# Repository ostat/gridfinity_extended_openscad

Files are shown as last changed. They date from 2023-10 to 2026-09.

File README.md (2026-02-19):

# Gridfinity Extended OpenSCAD Model

Welcome to the Gridfinity Extended OpenSCAD project! This is a recreation of Zack Freedman's Gridfinity system in OpenSCAD, designed to accurately reproduce the original Gridfinity bins while adding extra features and customization options.

## Features
- Accurate reproduction of Zack Freedman's original Gridfinity bins.
- Additional features and customization options for the base model.
- Extension patterns for further personalization and modularity.

## Getting Started
**Gridfinity Extended** is a set of OpenSCAD scripts for generating gridfinity related 3d models. There are two main ways to use the scripts.
- There is the official online customiser hosted at [makerworld](https://makerworld.com/en/models/481168-gridfinity-extended#profileId-1037829).
- Alternatively you can download and run the scripts locally.

### Option 1: Online customiser
You can also use the online version of this project hosted on [MakerWorld](https://makerworld.com). This option allows you to quickly experiment with the models without downloading anything.
The scripts uploaded to are fully featured and supported. I keep these updated with the latest version from GitHub.<br>
- Link: https://makerworld.com/en/models/481168-gridfinity-extended#profileId-1037829

### Option 2: Running locally
Running locally is how I recommend running the scripts. The scripts run faster and you can save your configuration. However but it does require you download and install the OpenSCAD software on your local machine.

1. Install OpenSCAD. This project relies on features available in the **OpenSCAD Developer Version**. Make sure to download it from [OpenSCAD Developer Version](https://openscad.org/downloads.html#snapshots).

2. Clone or download this repository to your local machine:
   ```bash
   git clone https://github.com/ostat/gridfinity_extended_openscad.git
   ```
   Alternatively, you can download the ZIP file from the repository page and extract it.

3. Enable OpenSCAD Features.
   - Open OpenSCAD application
   - Go to `Menu > Edit > Preferences`.
   - In the **Preferences** dialog go to the **Advanced** Tab:
     - Backend: select **manifold** option. Makes OpenSCAD faster.
   - An then go to the **Features** Tab:
     - Check **textmetrics**: Enables text related features for the base text.

4. Start Creating Your Own Gridfinity Parts
   - Open the SCAD library file you want to modify, e.g.: `gridfinity_baseplate.scad`
   - Make sure the Customizer window is visible:
      - View → Customizer (if not already open).
   - Render the model:
     - Press F5 for a quick preview
     - Press F6 for a full render
   - Adjust the parameters in the Customizer:
       - Parameter	Example Value	Description<BR>
        Width	2	Number of modules wide<BR>
        Depth	1	Number of modules deep<BR>
        Magnets	Enabled	Include magnet holes<BR>
        The model will update in real-time based on your changes.<BR>

5. Start exploring and customising the Gridfinity bins and extensions!

## Official Documentation
Official detailed documentation for each of the scripts can be found here [gridfinity-extended](https://docs.ostat.com/docs/openscad/gridfinity-extended)

## Scripts Overview
### Gridfinity Basic Cup
Script: `gridfinity_basic_cup.scad`<br>
This script creates the basic **Gridfinity Cup** with customizable dimensions, magnet slots, and divider options. It serves as the foundation for most Gridfinity bins.<br>
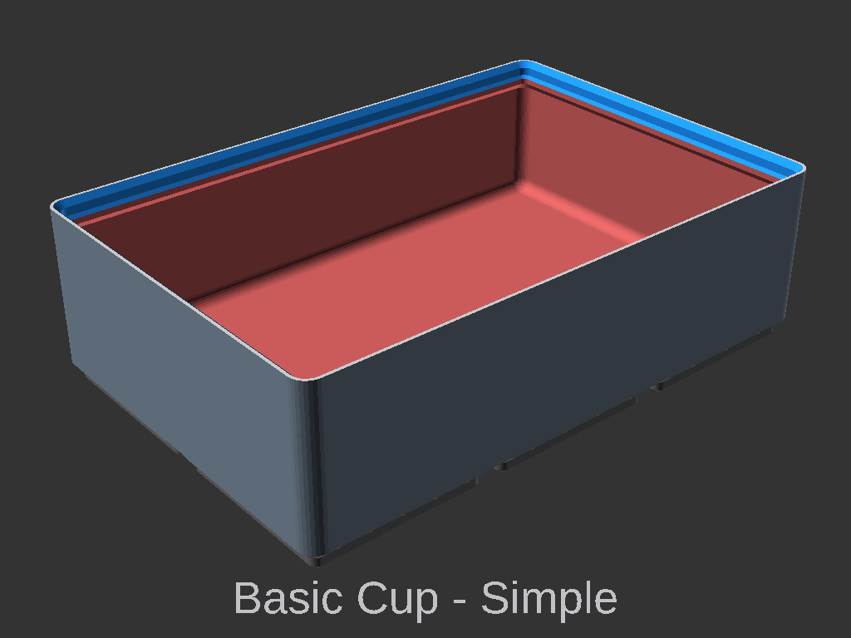
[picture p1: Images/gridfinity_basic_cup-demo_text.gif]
[](./Images/gridfinity_basic_cup-demo_text.gif)

### Gridfinity Base Plate
Script: `gridfinity_baseplate.scad`<br>
This script generates customizable Gridfinity baseplates. It includes options for magnet placement, weighted bases, and various styles to suit different applications.. Supports creating of customisable shapes.<br>
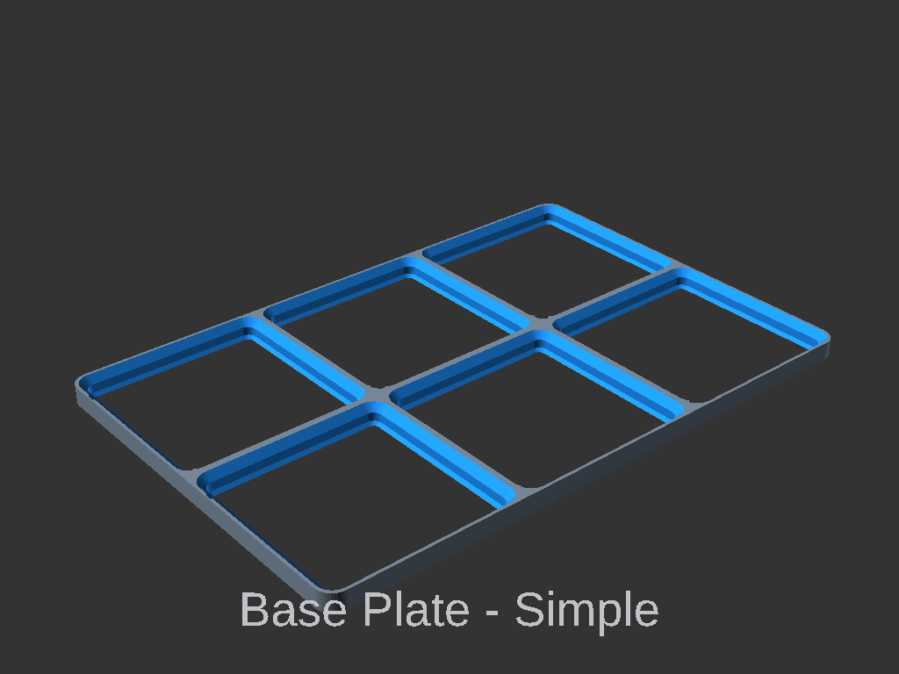
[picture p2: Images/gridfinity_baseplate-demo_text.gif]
[](./Images/gridfinity_baseplate-demo_text.gif)

### Gridfinity Drawers
Script: `gridfinity_drawers.scad`<br>
Creates modular drawers for Gridfinity bins. Includes options for drawer sizes, handles, and dividers, allowing for efficient organization.

### Gridfinity Extended Item Holder
Script: `gridfinity_item_holder.scad`<br>
Customisable Grid based item holder. Has built in dimensions of many common Memory card, Cartridges, batteries, and tools.<br>
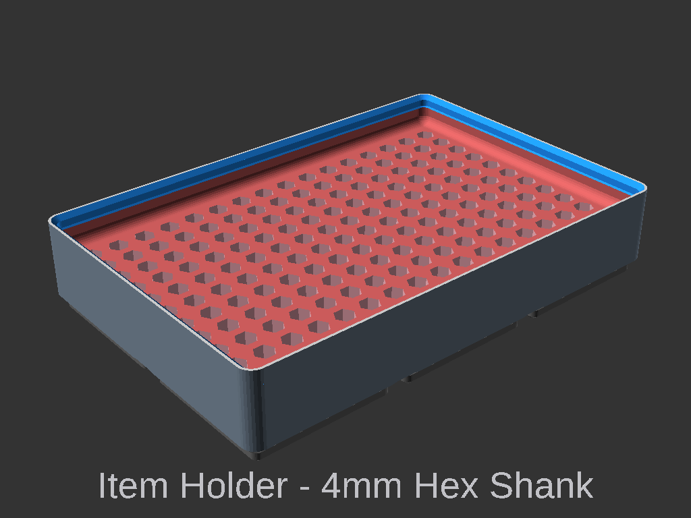
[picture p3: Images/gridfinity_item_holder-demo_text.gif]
[](./Images/gridfinity_item_holder-demo_text.gif)

### Gridfinity Extended Tray
Script: `gridfinity_tray.scad`<br>
Catch all tray for holding small items.<br>
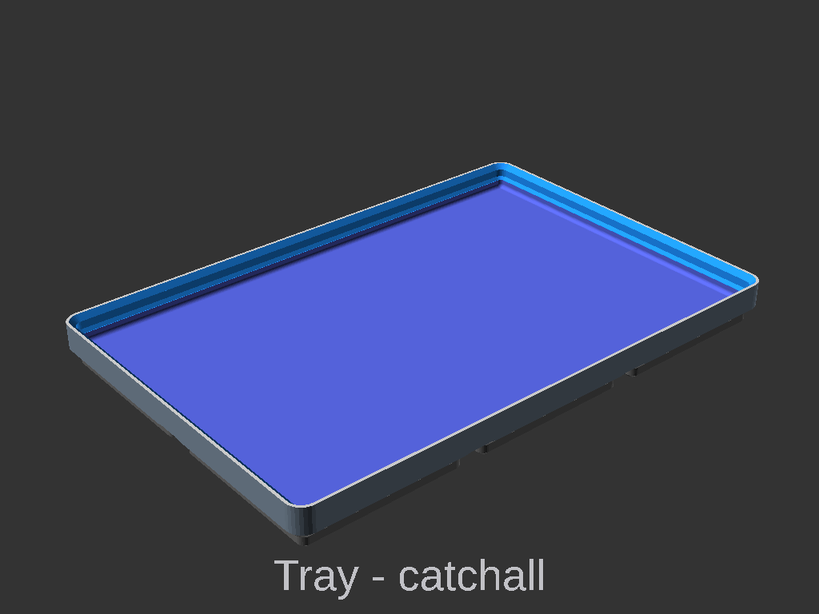
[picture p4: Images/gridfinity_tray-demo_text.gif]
[](./Images/gridfinity_tray-demo_text.gif)

### Gridfinity Marble Run
Script: `gridfinity_marble.scad`<br>
A fun and creative script for generating marble runs that are compatible with the Gridfinity system. Great for educational or entertainment purposes.

### gridfinity_lid.scad
Creates lids for Gridfinity bins. Includes options for sliding lids, hinged lids, and magnet-secured lids to keep items secure.

### gridfinity_silverware.scad
Creates organizers for silverware that fit within the Gridfinity system. Perfect for kitchen organization.

### gridfinity_chess.scad
Generates a Gridfinity-compatible chess set. Each piece is designed to fit within the Gridfinity system, making it easy to store and organise.

### gridfinity_sliding_lid.scad
A specialized script for creating sliding lids for Gridfinity bins. Includes options for locking mechanisms and smooth sliding functionality.

### gridfinity_socket_holder.scad
Generates holders for sockets and other tools, ensuring compatibility with the Gridfinity system. Includes predefined dimensions for common socket sizes.

### gridfinity_baseplate_flsun_q5.scad
A specialized version of the baseplate script tailored for the FLsun Q5 3D printer. It ensures compatibility with the printer's build dimensions and features.

## How to Contribute

I welcome contributions to help improve and expand the Gridfinity Extended library! Here’s how you can contribute:

1. **Fork the Repository**: Create your own fork of the project to make changes.
2. **Make Improvements**: Add new features, fix bugs, or improve documentation.
3. **Submit a Pull Request**: Once your changes are ready, submit a pull request to the main repository for review.

## Feedback and Support

Your feedback is invaluable! If you have suggestions, issues, or ideas for improvement, feel free to open an issue or contribute to the project.

---

Thank you for exploring the Gridfinity Extended OpenSCAD project! I hope you enjoy customising and expanding your Gridfinity system.

This project is based on work by Zack Freedman's of [voidstarlab](https://www.voidstarlab.com/) and [vector76](https://github.com/vector76/)'s [gridfinity_openscad](https://github.com/vector76/gridfinity_openscad)

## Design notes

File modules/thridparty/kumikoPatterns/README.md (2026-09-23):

# Kumiko Patterns

This is an OpenSCAD implementation of various traditional japanese Kumiko patterns.
They are all based on the triangle shape and add various infills.
Implemented right now are the following patterns:

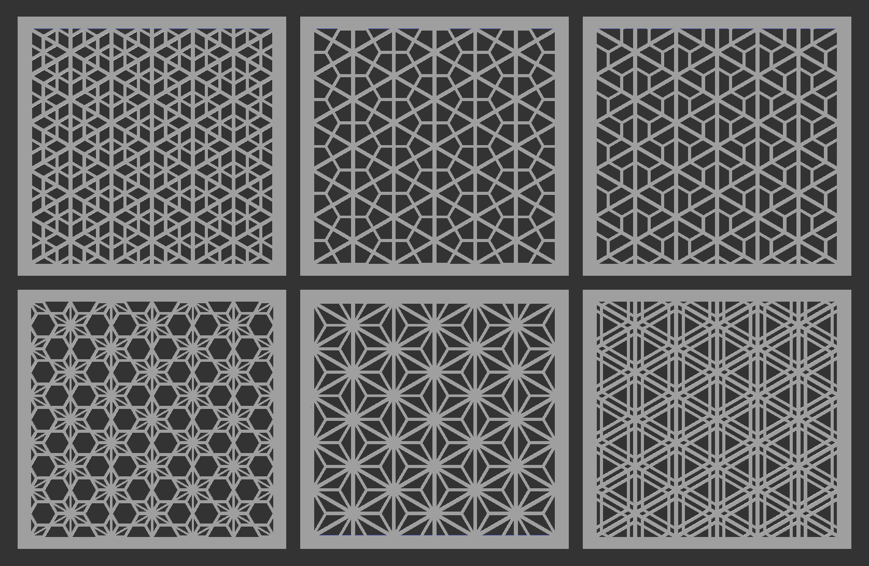
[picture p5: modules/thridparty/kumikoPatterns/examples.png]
examples of kumiko patterns


- Mikado
- Tsumiishi Kikko
- Bishamon Kikkou
- Tobi Asanoha
- Asanoha
- Goma

(left to right, top to bottom)

I am sorry if I butchered those names or got the naming entirely wrong, 
please contact me if I need to fix them or just create a PR :)

## Usage

To use those patterns in your OpenSCAD scripts, copy the `kumiko.scad` file 
into the same directory as your script, then include it with `use <kumiko.scad>`.
To create a pattern of your choice, invoke the respective module like so:

`goma(cellSize=20, widthInCells=6, heightInCells=5, gap=3, strength=1.6, fillingStrength=1.2);`

See the [demo.scad](demo.scad) file for more usage examples.

- `cellSize` is the edge length of the base triangle shape
- `widthInCells` is the width of the created pattern, in full triangles. A value of 4 will create a pattern that is 4 triangles wide.
- `heightInCells` is similar to `widthInCells`, just for the height of the pattern.
- `gap` is specific to the Goma pattern and specifies the space between parallel lines, not taking the line strength into account.
- `strength` is the width of the base triangle lines.
- `fillingStrength` is the width of the lines inside the base triangles.

## Implementation notes

The triangle-based patterns are created by first building a base triangle pattern, 
and then building the infill patterns by rotating a given line pattern 
around the intersection points of the base triangles.

If you want to implement additional point-symmetric patterns, 
please align the implementation with the existing ones to ease code understandability and maintainability.
If you want to implement patterns not based on non-overlapping triangles,
you are free to do it any way you like (until a common pattern is established).

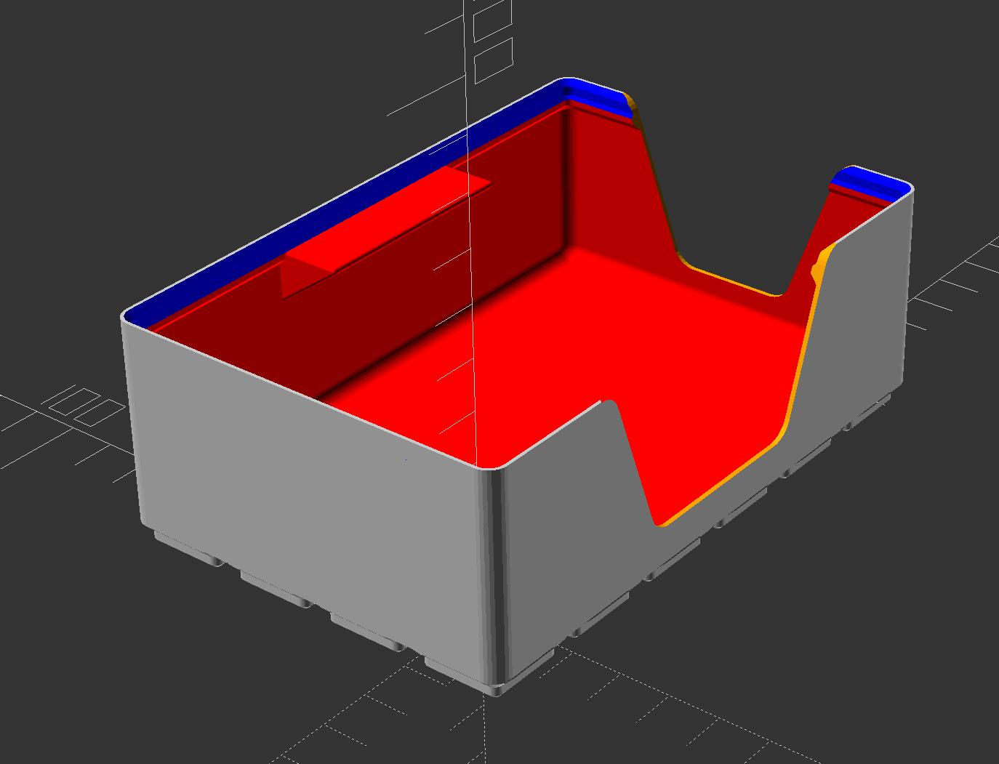
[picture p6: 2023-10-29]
Images/basic_cup_wall_cutout.jpg

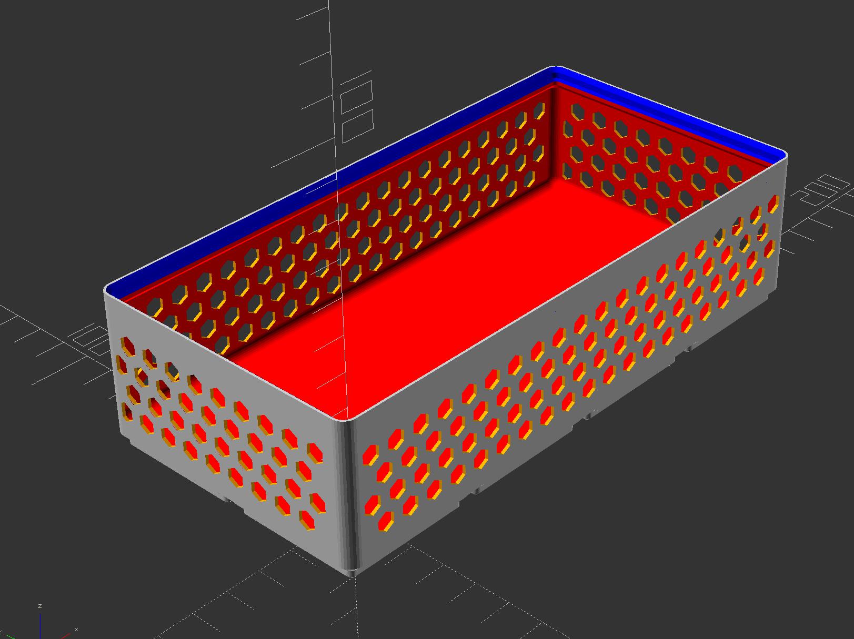
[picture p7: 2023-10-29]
Images/basic_cup_wall_pattern.jpg

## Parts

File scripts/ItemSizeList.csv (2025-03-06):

type | code | shape | diameter | width | thickness | height | depthneeded | description | source
battery | aaaa | round | 8.3 | 0 | 0 | 42.5 | 10.625 | AAAA cell | https://en.wikipedia.org/wiki/List_of_battery_sizes
battery | aaa | round | 10.5 | 0 | 0 | 44.5 | 11.125 | AAA cell | https://en.wikipedia.org/wiki/List_of_battery_sizes
battery | aa | round | 14.5 | 0 | 0 | 50.5 | 12.625 | AA cell | https://en.wikipedia.org/wiki/List_of_battery_sizes
battery | 9v | square | 1 | 17.5 | 26.5 | 48.5 | 12.5 | 9v | https://en.wikipedia.org/wiki/List_of_battery_sizes
battery | c | round | 26.2 | 0 | 0 | 50 | 12.5 | C cell | https://en.wikipedia.org/wiki/List_of_battery_sizes
battery | d | round | 34.2 | 0 | 0 | 61.5 | 15.375 | d cell | https://en.wikipedia.org/wiki/List_of_battery_sizes
battery | 7540cell | round | 7.5 | 0 | 0 | 40 | 10 | 7540 cell | https://en.wikipedia.org/wiki/List_of_battery_sizes
battery | 8570cell | round | 8.5 | 0 | 0 | 70 | 17.5 | 8570 cell | https://en.wikipedia.org/wiki/List_of_battery_sizes
battery | 10180cell | round | 10 | 0 | 0 | 18 | 4.5 | 10180 cell | https://en.wikipedia.org/wiki/List_of_battery_sizes
battery | 10280cell | round | 10 | 0 | 0 | 28 | 7 | 10280 cell | https://en.wikipedia.org/wiki/List_of_battery_sizes
battery | 10440cell | round | 10 | 0 | 0 | 44 | 11 | 10440 cell | https://en.wikipedia.org/wiki/List_of_battery_sizes
battery | 10850cell | round | 10 | 0 | 0 | 85 | 21.25 | 10850 cell | https://en.wikipedia.org/wiki/List_of_battery_sizes
battery | 13400cell | round | 13 | 0 | 0 | 40 | 10 | 13400 cell | https://en.wikipedia.org/wiki/List_of_battery_sizes
battery | 14250cell | round | 14 | 0 | 0 | 25 | 6.25 | 14250 cell | https://en.wikipedia.org/wiki/List_of_battery_sizes
battery | 14300cell | round | 14 | 0 | 0 | 30 | 7.5 | 14300 cell | https://en.wikipedia.org/wiki/List_of_battery_sizes
battery | 14430cell | round | 14 | 0 | 0 | 43 | 10.75 | 14430 cell | https://en.wikipedia.org/wiki/List_of_battery_sizes
battery | 14500cell | round | 14 | 0 | 0 | 53 | 13.25 | 14500 cell | https://en.wikipedia.org/wiki/List_of_battery_sizes
battery | 14650cell | round | 14 | 0 | 0 | 65 | 16.25 | 14650 cell | https://en.wikipedia.org/wiki/List_of_battery_sizes
battery | 15270cell | round | 15 | 0 | 0 | 27 | 6.75 | 15270 cell | https://en.wikipedia.org/wiki/List_of_battery_sizes
battery | 16340cell | round | 16 | 0 | 0 | 34 | 8.5 | 16340 cell | https://en.wikipedia.org/wiki/List_of_battery_sizes
battery | 16650cell | round | 16 | 0 | 0 | 65 | 16.25 | 16650 cell | https://en.wikipedia.org/wiki/List_of_battery_sizes
battery | 17500cell | round | 17 | 0 | 0 | 50 | 12.5 | 17500 cell | https://en.wikipedia.org/wiki/List_of_battery_sizes
battery | 17650cell | round | 17 | 0 | 0 | 65 | 16.25 | 17650 cell | https://en.wikipedia.org/wiki/List_of_battery_sizes
battery | 17670cell | round | 17 | 0 | 0 | 67 | 16.75 | 17670 cell | https://en.wikipedia.org/wiki/List_of_battery_sizes
battery | 18350cell | round | 18 | 0 | 0 | 35 | 8.75 | 18350 cell | https://en.wikipedia.org/wiki/List_of_battery_sizes
battery | 18490cell | round | 18 | 0 | 0 | 49 | 12.25 | 18490 cell | https://en.wikipedia.org/wiki/List_of_battery_sizes
battery | 18500cell | round | 18 | 0 | 0 | 50 | 12.5 | 18500 cell | https://en.wikipedia.org/wiki/List_of_battery_sizes
battery | 18650cell | round | 18 | 0 | 0 | 65 | 16.25 | 18650 cell | https://en.wikipedia.org/wiki/List_of_battery_sizes
battery | 20700cell | round | 20 | 0 | 0 | 70 | 17.5 | 20700 cell | https://en.wikipedia.org/wiki/List_of_battery_sizes
battery | 21700cell | round | 21 | 0 | 0 | 70 | 17.5 | 21700 cell | https://en.wikipedia.org/wiki/List_of_battery_sizes
battery | 25500cell | round | 25 | 0 | 0 | 50 | 12.5 | 25500 cell | https://en.wikipedia.org/wiki/List_of_battery_sizes
battery | 26500cell | round | 26 | 0 | 0 | 50 | 12.5 | 26500 cell | https://en.wikipedia.org/wiki/List_of_battery_sizes
battery | 26650cell | round | 26 | 0 | 0 | 65 | 16.25 | 26650 cell | https://en.wikipedia.org/wiki/List_of_battery_sizes
battery | 26700cell | round | 26 | 0 | 0 | 70 | 17.5 | 26700 cell | https://en.wikipedia.org/wiki/List_of_battery_sizes
battery | 26800cell | round | 26 | 0 | 0 | 80 | 20 | 26800 cell | https://en.wikipedia.org/wiki/List_of_battery_sizes
battery | 32600cell | round | 32 | 0 | 0 | 60 | 15 | 32600 cell | https://en.wikipedia.org/wiki/List_of_battery_sizes
battery | 32650cell | round | 32 | 0 | 0 | 67.7 | 16.925 | 32650 cell | https://en.wikipedia.org/wiki/List_of_battery_sizes
battery | 32700cell | round | 32 | 0 | 0 | 70 | 17.5 | 32700 cell | https://en.wikipedia.org/wiki/List_of_battery_sizes
battery | 38120cell | round | 38 | 0 | 0 | 120 | 30 | 38120 cell | https://en.wikipedia.org/wiki/List_of_battery_sizes
battery | 38140cell | round | 38 | 0 | 0 | 140 | 35 | 38140 cell | https://en.wikipedia.org/wiki/List_of_battery_sizes
battery | 40152cell | round | 40 | 0 | 0 | 152 | 38 | 40152 cell | https://en.wikipedia.org/wiki/List_of_battery_sizes
battery | 4680cell | round | 46 | 0 | 0 | 80 | 20 | 4680 cell | https://en.wikipedia.org/wiki/List_of_battery_sizes
buttoncell | CR927 | halfround | 0 | 9.5 | 2.7 | 0 | 0 | CR927 cell | https://en.wikipedia.org/wiki/List_of_battery_sizes
buttoncell | CR1025 | halfround | 0 | 10 | 2.5 | 0 | 0 | CR1025 cell | https://en.wikipedia.org/wiki/List_of_battery_sizes
buttoncell | CR1130 | halfround | 0 | 11.5 | 3 | 0 | 0 | CR1130 cell | https://en.wikipedia.org/wiki/List_of_battery_sizes
buttoncell | CR1216 | halfround | 0 | 12.5 | 1.6 | 0 | 0 | CR1216 cell | https://en.wikipedia.org/wiki/List_of_battery_sizes
buttoncell | CR1220 | halfround | 0 | 12.5 | 2 | 0 | 0 | CR1220 cell | https://en.wikipedia.org/wiki/List_of_battery_sizes
buttoncell | CR1225 | halfround | 0 | 12.5 | 2.5 | 0 | 0 | CR1225 cell | https://en.wikipedia.org/wiki/List_of_battery_sizes
buttoncell | CR1616 | halfround | 0 | 16 | 1.6 | 0 | 0 | CR1616 cell | https://en.wikipedia.org/wiki/List_of_battery_sizes
buttoncell | CR1620 | halfround | 0 | 16 | 2 | 0 | 0 | CR1620 cell | https://en.wikipedia.org/wiki/List_of_battery_sizes
buttoncell | CR1632 | halfround | 0 | 16 | 3.2 | 0 | 0 | CR1632 cell | https://en.wikipedia.org/wiki/List_of_battery_sizes
buttoncell | CR2012 | halfround | 0 | 20 | 1.2 | 0 | 0 | CR2012 cell | https://en.wikipedia.org/wiki/List_of_battery_sizes
buttoncell | CR2016 | halfround | 0 | 20 | 1.6 | 0 | 0 | CR2016 cell | https://en.wikipedia.org/wiki/List_of_battery_sizes
buttoncell | CR2020 | halfround | 0 | 20 | 2 | 0 | 0 | CR2020 cell | https://en.wikipedia.org/wiki/List_of_battery_sizes
buttoncell | CR2025 | halfround | 0 | 20 | 2.5 | 0 | 0 | CR2025 cell | https://en.wikipedia.org/wiki/List_of_battery_sizes
buttoncell | CR2032 | halfround | 0 | 20 | 3.2 | 0 | 0 | CR2032 cell | https://en.wikipedia.org/wiki/List_of_battery_sizes
buttoncell | CR2040 | halfround | 0 | 20 | 4 | 0 | 0 | CR2040 cell | https://en.wikipedia.org/wiki/List_of_battery_sizes
buttoncell | CR2050 | halfround | 0 | 20 | 5 | 0 | 0 | CR2050 cell | https://en.wikipedia.org/wiki/List_of_battery_sizes
buttoncell | CR2320 | halfround | 0 | 23 | 2 | 0 | 0 | CR2320 cell | https://en.wikipedia.org/wiki/List_of_battery_sizes
buttoncell | CR2325 | halfround | 0 | 23 | 2.5 | 0 | 0 | CR2325 cell | https://en.wikipedia.org/wiki/List_of_battery_sizes
buttoncell | CR2330 | halfround | 0 | 23 | 3 | 0 | 0 | CR2330 cell | https://en.wikipedia.org/wiki/List_of_battery_sizes
buttoncell | BR2335 | halfround | 0 | 23 | 3.5 | 0 | 0 | BR2335 cell | https://en.wikipedia.org/wiki/List_of_battery_sizes
buttoncell | CR2354 | halfround | 0 | 23 | 5.4 | 0 | 0 | CR2354 cell | https://en.wikipedia.org/wiki/List_of_battery_sizes
buttoncell | CR2412 | halfround | 0 | 24.5 | 1.2 | 0 | 0 | CR2412 cell | https://en.wikipedia.org/wiki/List_of_battery_sizes
buttoncell | CR2430 | halfround | 0 | 24.5 | 3 | 0 | 0 | CR2430 cell | https://en.wikipedia.org/wiki/List_of_battery_sizes
buttoncell | CR2450 | halfround | 0 | 24.5 | 5 | 0 | 0 | CR2450 cell | https://en.wikipedia.org/wiki/List_of_battery_sizes
buttoncell | CR2477 | halfround | 0 | 24.5 | 7.7 | 0 | 0 | CR2477 cell | https://en.wikipedia.org/wiki/List_of_battery_sizes
buttoncell | CR3032 | halfround | 0 | 30 | 3.2 | 0 | 0 | CR3032 cell | https://en.wikipedia.org/wiki/List_of_battery_sizes
buttoncell | CR11108 | halfround | 0 | 11.6 | 10.8 | 0 | 0 | CR11108 cell | https://en.wikipedia.org/wiki/List_of_battery_sizes
tool | 4hexshank | hex | 4 | 0 | 0 | 20 | 5 | 4mm Hex Shank
tool | 1/4hexshank | hex | 6.35 | 0 | 0 | 15 | 8 | 1/4 Hex Shank
tool | 1/4hexshanklong | hex | 6.35 | 0 | 0 | 40 | 15 | 1/4 Hex Long Shank
tool | 5/16hexshank | hex | 7.94 | 0 | 0 | 0 | 7 | 5/16 Hex Shank
tool | 3/8hexshank | hex | 9.52 | 0 | 0 | 0 | 10 | 3/8 Hex Shank
tool | 1/2shank | round | 12.7 | 0 | 0 | 50 | 20 | 1/2 inch router bit | https://en.wikipedia.org/wiki/Router_(woodworking)
tool | 12shank | round | 12 | 0 | 0 | 50 | 20 | 12mm router bit | https://en.wikipedia.org/wiki/Router_(woodworking)
tool | 10shank | round | 10 | 0 | 0 | 50 | 20 | 10mm router bit | https://en.wikipedia.org/wiki/Router_(woodworking)
tool | 3/8shank | round | 9.525 | 0 | 0 | 50 | 20 | 3/8 inch router bit | https://en.wikipedia.org/wiki/Router_(woodworking)
tool | 8shank | round | 8 | 0 | 0 | 50 | 20 | 8mm router bit | https://en.wikipedia.org/wiki/Router_(woodworking)
tool | 1/4shank | round | 6.35 | 0 | 0 | 50 | 20 | 1/4 inch router bit | https://en.wikipedia.org/wiki/Router_(woodworking)
tool | 6shank | round | 6 | 0 | 0 | 40 | 15 | 6mm router bit | https://en.wikipedia.org/wiki/Router_(woodworking)
tool | 1/8shank | round | 3.2 | 0 | 0 | 40 | 15 | 1/8 inch Dremel router bit | https://en.wikipedia.org/wiki/Router_(woodworking)
card | multicard | square | 0 | 0 | 0 | 0 | 0 | Multi card slot
card | compactflashi | square | 0 | 43 | 3.3 | 36 | 9 | CompactFlash, Type I | https://en.wikipedia.org/wiki/Comparison_of_memory_cards
card | compactflashii | square | 0 | 43 | 5 | 36 | 9 | CompactFlash, Type II | https://en.wikipedia.org/wiki/Comparison_of_memory_cards
card | smartmedia | square | 0 | 37 | 0.76 | 45 | 11.25 | SmartMedia | https://en.wikipedia.org/wiki/Comparison_of_memory_cards
card | mmc | square | 0 | 24 | 1.4 | 32 | 8 | MMC, MMCplus | https://en.wikipedia.org/wiki/Comparison_of_memory_cards
card | mmcmobile | square | 0 | 24 | 1.4 | 18 | 4.5 | RS-MMC, MMCmobile | https://en.wikipedia.org/wiki/Comparison_of_memory_cards
card | mmcmicro | square | 0 | 14 | 1.1 | 12 | 3 | MMCmicro | https://en.wikipedia.org/wiki/Comparison_of_memory_cards
card | sd | square | 0 | 24 | 2.1 | 32 | 18 | SD, SDHC, SDXC, SDIO, MicroP2 | https://en.wikipedia.org/wiki/Comparison_of_memory_cards
card | minisd | square | 0 | 20 | 1.4 | 21.5 | 10 | miniSD, miniSDHC, miniSDIO | https://en.wikipedia.org/wiki/Comparison_of_memory_cards
card | microsd | square | 0 | 11 | 0.7 | 15 | 9 | microSD, microSDHC, microSDXC | https://en.wikipedia.org/wiki/Comparison_of_memory_cards
card | memorystickstandard | square | 0 | 21.5 | 2.8 | 50 | 12.5 | Memory Stick Standard, PRO | https://en.wikipedia.org/wiki/Comparison_of_memory_cards
card | memorystickduo | square | 0 | 20 | 1.6 | 31 | 7.75 | Memory Stick Duo, PRO Duo, PRO-HG, XC | https://en.wikipedia.org/wiki/Comparison_of_memory_cards
card | memorystickmicro | square | 0 | 12.5 | 1.2 | 15 | 3.75 | Memory Stick Micro (M2), XC | https://en.wikipedia.org/wiki/Comparison_of_memory_cards
card | nano | square | 0 | 12.3 | 0.7 | 8.8 | 2.2 | Nano Memory | https://en.wikipedia.org/wiki/Comparison_of_memory_cards
card | psvita | square | 0 | 15 | 1.6 | 12.5 | 3.125 | PS Vita Memory Card | https://en.wikipedia.org/wiki/Comparison_of_memory_cards
card | xqd | square | 0 | 38.5 | 3.8 | 29.8 | 7.45 | XQD card | https://en.wikipedia.org/wiki/Comparison_of_memory_cards
card | xd | square | 0 | 25 | 1.78 | 20 | 5 | xD | https://en.wikipedia.org/wiki/Comparison_of_memory_cards
card | usba | square | 0 | 12 | 4.5 | 13 | 13 | USB A
card | usbc | square | 0 | 8.5 | 4 | 0 | 10 | USB C
cartridge | atari800 | square | 0 | 68 | 21 | 77 | 19.25 | Atari 800 | https://www.reddit.com/r/gamecollecting/comments/23stkf/q_dimensions_for_game_cartridges/
cartridge | atari2600 | square | 0 | 81 | 19 | 87 | 21.75 | Atari 2600/7800/Colecovision | https://www.reddit.com/r/gamecollecting/comments/23stkf/q_dimensions_for_game_cartridges/
cartridge | atari5200 | square | 0 | 104 | 20 | 112 | 28 | Atari 5200 | https://www.reddit.com/r/gamecollecting/comments/23stkf/q_dimensions_for_game_cartridges/
cartridge | atari7800 | square | 0 | 81 | 19 | 87 | 21.75 | Atari 7800 | https://www.reddit.com/r/gamecollecting/comments/23stkf/q_dimensions_for_game_cartridges/
cartridge | commodore | square | 0 | 79 | 17 | 139 | 34.75 | Commodore Vic20 | https://www.reddit.com/r/gamecollecting/comments/23stkf/q_dimensions_for_game_cartridges/
cartridge | magnavoxodyssey | square | 0 | 100 | 5.5 | 60 | 15 | Magnavox Odyssey | https://www.reddit.com/r/gamecollecting/comments/23stkf/q_dimensions_for_game_cartridges/
cartridge | magnavoxodysseymulticard | square | 0 | 105 | 15 | 110 | 27.5 | Magnavox Odyssey (multicard) | https://www.reddit.com/r/gamecollecting/comments/23stkf/q_dimensions_for_game_cartridges/
cartridge | magnavoxodyssey2 | square | 0 | 80 | 21 | 127 | 31.75 | Magnavox Odyssey2 | https://www.reddit.com/r/gamecollecting/comments/23stkf/q_dimensions_for_game_cartridges/
cartridge | mattelintellivision | square | 0 | 68 | 16 | 88 | 22 | Mattel Intellivision I & II | https://www.reddit.com/r/gamecollecting/comments/23stkf/q_dimensions_for_game_cartridges/
cartridge | nintendofamicom | square | 0 | 71 | 17 | 108 | 27 | Nintendo Famicom | https://www.reddit.com/r/gamecollecting/comments/23stkf/q_dimensions_for_game_cartridges/
cartridge | nintendofamicomdisk | square | 0 | 76 | 4 | 90 | 22.5 | Nintendo Famicom Disk | https://www.reddit.com/r/gamecollecting/comments/23stkf/q_dimensions_for_game_cartridges/
cartridge | nintendosuperfamicom | square | 0 | 127 | 20 | 86 | 21.5 | Nintendo Super Famicom / SNES (Pal) | https://www.reddit.com/r/gamecollecting/comments/23stkf/q_dimensions_for_game_cartridges/
cartridge | nes | square | 0 | 120 | 17 | 134 | 33.5 | NES | https://www.reddit.com/r/gamecollecting/comments/23stkf/q_dimensions_for_game_cartridges/
cartridge | snes | square | 0 | 136 | 20 | 87.7 | 21.925 | SNES | https://www.reddit.com/r/gamecollecting/comments/23stkf/q_dimensions_for_game_cartridges/
cartridge | nintendo64 | square | 0 | 116 | 18 | 75 | 18.75 | Nintendo 64 | https://www.reddit.com/r/gamecollecting/comments/23stkf/q_dimensions_for_game_cartridges/
cartridge | nintendogb | square | 0 | 57 | 7.5 | 65.5 | 16.375 | Nintendo GB | https://www.reddit.com/r/gamecollecting/comments/23stkf/q_dimensions_for_game_cartridges/
cartridge | nintendogbc | square | 0 | 57 | 9 | 65.5 | 16.375 | Nintendo GBC | https://www.reddit.com/r/gamecollecting/comments/23stkf/q_dimensions_for_game_cartridges/
cartridge | nintendogba | square | 0 | 35 | 6 | 57 | 14.25 | Nintendo GBA | https://www.reddit.com/r/gamecollecting/comments/23stkf/q_dimensions_for_game_cartridges/
cartridge | nintendods | square | 0 | 33 | 3.8 | 35 | 8.75 | Nintendo DS | https://www.reddit.com/r/gamecollecting/comments/23stkf/q_dimensions_for_game_cartridges/
cartridge | nintendo2ds | square | 0 | 35 | 3.8 | 35 | 8.75 | Nintendo 2DS/3DS | https://www.reddit.com/r/gamecollecting/comments/23stkf/q_dimensions_for_game_cartridges/
cartridge | nintendovb | square | 0 | 75 | 7 | 68 | 17 | Nintendo Virtual Boy | https://www.reddit.com/r/gamecollecting/comments/23stkf/q_dimensions_for_game_cartridges/
cartridge | nintendoswitch | square | 0 | 21 | 3 | 31 | 7.75 | Nintendo Switch | https://www.reddit.com/r/gamecollecting/comments/23stkf/q_dimensions_for_game_cartridges/
cartridge | segagamegear | square | 0 | 66 | 10 | 68 | 17 | Sega Game Gear | https://www.reddit.com/r/gamecollecting/comments/23stkf/q_dimensions_for_game_cartridges/
cartridge | segagenesis | square | 0 | 118 | 15 | 68 | 17 | Sega Genesis | https://www.reddit.com/r/gamecollecting/comments/23stkf/q_dimensions_for_game_cartridges/
cartridge | segagenesistall | square | 0 | 96 | 16 | 88 | 22 | Sega Genesis (tall cart) | https://www.reddit.com/r/gamecollecting/comments/23stkf/q_dimensions_for_game_cartridges/
cartridge | segamegadrive | square | 0 | 93 | 17 | 67 | 16.75 | Sega MegaDrive | https://www.reddit.com/r/gamecollecting/comments/23stkf/q_dimensions_for_game_cartridges/
cartridge | segamegadrivecodemasters | square | 0 | 109 | 17 | 75 | 18.75 | Sega MegaDrive Codemasters | https://www.reddit.com/r/gamecollecting/comments/23stkf/q_dimensions_for_game_cartridges/
cartridge | segamastersystem | square | 0 | 69 | 17 | 108 | 27 | Sega Master System | https://www.reddit.com/r/gamecollecting/comments/23stkf/q_dimensions_for_game_cartridges/
cartridge | sega32x | square | 0 | 72 | 16 | 111 | 27.75 | Sega 32x | https://www.reddit.com/r/gamecollecting/comments/23stkf/q_dimensions_for_game_cartridges/
cartridge | segacard | square | 0 | 84 | 2 | 53 | 13.25 | Sega Card/TG16 | https://www.reddit.com/r/gamecollecting/comments/23stkf/q_dimensions_for_game_cartridges/
cartridge | segapico | square | 0 | 181 | 15 | 223 | 55.75 | Sega Pico | https://www.reddit.com/r/gamecollecting/comments/23stkf/q_dimensions_for_game_cartridges/
cartridge | sonyumd | round | 0 | 64 | 0 | 4.2 | 1.05 | Sony UMD | https://www.reddit.com/r/gamecollecting/comments/23stkf/q_dimensions_for_game_cartridges/
cartridge | sonypsvita | square | 0 | 22 | 2 | 30 | 7.5 | Sony PS Vita | https://www.reddit.com/r/gamecollecting/comments/23stkf/q_dimensions_for_game_cartridges/
cartridge | sonypsvitamemcard | square | 0 | 12.5 | 1.6 | 15 | 3.75 | Sony PS Vita (Mem Card) | https://www.reddit.com/r/gamecollecting/comments/23stkf/q_dimensions_for_game_cartridges/
cartridge | necpcehucard | square | 0 | 53 | 2 | 84 | 21 | NEC PCE HuCard | https://www.reddit.com/r/gamecollecting/comments/23stkf/q_dimensions_for_game_cartridges/
cartridge | snkneogeoaes | square | 0 | 146.05 | 31.75 | 190.5 | 47.625 | SNK Neo Geo AES | https://www.reddit.com/r/gamecollecting/comments/23stkf/q_dimensions_for_game_cartridges/
cartridge | snkneogeomvs | square | 0 | 145 | 35 | 185 | 46.25 | SNK Neo Geo MVS | https://www.reddit.com/r/gamecollecting/comments/23stkf/q_dimensions_for_game_cartridges/
cartridge | bandai | square | 0 | 41 | 6 | 66 | 16.5 | Bandai Wonderswan/Color | https://www.reddit.com/r/gamecollecting/comments/23stkf/q_dimensions_for_game_cartridges/
cartridge | msx | square | 0 | 109 | 16.8 | 69.4 | 17.35 | MSX | https://www.reddit.com/r/gamecollecting/comments/23stkf/q_dimensions_for_game_cartridges/

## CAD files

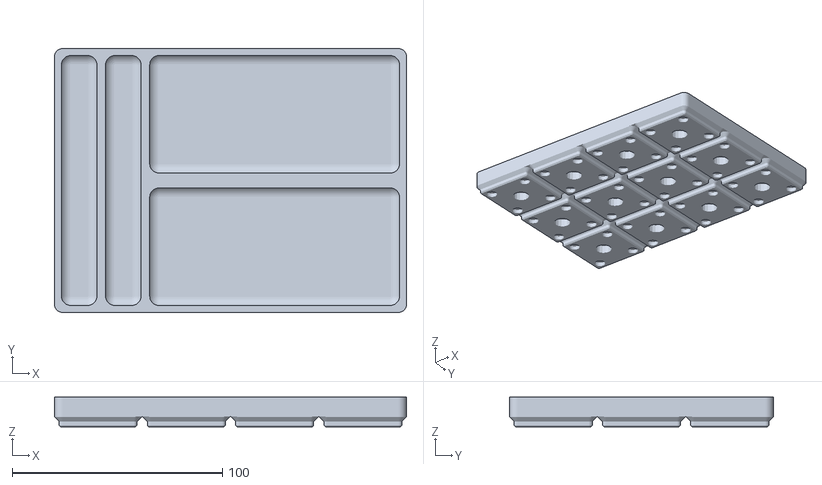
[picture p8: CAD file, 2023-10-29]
Renders/gridfinity_tray.stl
167.5 x 125.5 x 14.2

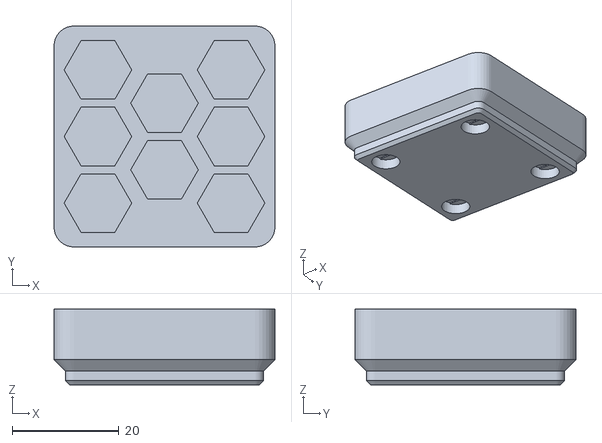
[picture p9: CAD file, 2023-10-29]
Renders/gridfinity_item_holder.stl
41.5 x 41.5 x 14.2

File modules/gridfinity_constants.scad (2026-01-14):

// dimensions as declared on https://gridfinity.xyz/specification/

//Gridfinity grid size
gf_pitch = 42;
//Gridfinity height size
gf_zpitch = 7;

gf_taper_angle = 45;

// cup
gf_cup_corner_radius = 3.75;
gf_cup_floor_thickness = 0.7;  

// CupBase
gf_cupbase_lower_taper_height = 0.8;
gf_cupbase_riser_height = 1.8;
gf_cupbase_upper_taper_height = 2.15;
gf_cupbase_magnet_position = 4.8; 
gf_cupbase_screw_diameter = 3; 
gf_cupbase_screw_depth = 6;
gf_magnet_diameter = 6.5;
gf_magnet_thickness = 2.4;
gf_base_grid_clearance_height = 3.5;

//stacking lips
// Standard lip
// \        gf_lip_upper_taper_height 
//  |       gf_lip_riser_height
//   \      gf_lip_lower_taper_height
//    |     gf_lip_height
//   /      gf_lip_support_taper_height
//  /
// /
///
// Reduced lip
// \        gf_lip_upper_taper_height 
//  |       gf_lip_riser_height
// /        gf_lip_reduced_support_taper_height
/// 
gf_lip_lower_taper_height = 0.7;
gf_lip_riser_height = 1.8;
gf_lip_upper_taper_height = 1.9;
gf_lip_height = 1.2;
//gf_lip_support_taper_height = 2.5;
//gf_lip_reduced_support_taper_height = 1.9;

// base plate
gf_baseplate_lower_taper_height = 0.7;
gf_baseplate_riser_height = 1.8;
gf_baseplate_upper_taper_height = 2.15;
gf_baseplate_magnet_od = 6.5;
gf_baseplate_magnet_thickness = 2.4;

// top lip height 4.4mm
gf_Lip_Height = 4.4-0.6;//gf_lip_lower_taper_height + gf_lip_riser_height + gf_lip_upper_taper_height;

// cupbase height 4.75mm + 0.25.
function gfBaseHeight() = gf_cupbase_lower_taper_height + gf_cupbase_riser_height + gf_cupbase_upper_taper_height+0.25; //results in 5
gf_min_base_height = gfBaseHeight(); 

// base heighttop lip height 4.4mm
function gfBasePlateHeight() = gf_baseplate_lower_taper_height + gf_baseplate_riser_height + gf_baseplate_upper_taper_height;

 

// old names, that will get replaced
/*
gridfinity_lip_height = gf_Lip_Height; 
gridfinity_corner_radius = gf_cup_corner_radius ; 
gridfinity_zpitch = env_pitch().z;
minFloorThickness = gf_cup_floor_thickness;  
const_magnet_height = gf_magnet_thickness;
*/

//Small amount to add to prevent clipping in openSCAD
fudgeFactor = 0.01;

color_cup = "LightSlateGray";
color_divider = "Gainsboro"; //LemonChiffon
color_topcavity = "Green";//"SteelBlue";
color_label = "DarkCyan";
color_cupcavity = "LightGreen"; //IndianRed
color_wallcutout = "SandyBrown";
color_basehole = "DarkSlateGray";
color_base = "DimGray";
color_extension = "lightpink";
color_text = "Yellow"; //Gold
color_cut = "Black";
color_lid = "MediumAquamarine";

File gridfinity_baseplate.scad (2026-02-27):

// include instead of use, so we get the pitch
include <modules/gridfinity_constants.scad>
use <modules/module_gridfinity_block.scad>
use <modules/module_gridfinity_baseplate.scad>
use <modules/module_gridfinity_frame_connectors.scad>

// Plate Style
Base_Plate_Options = "default";//[default:Efficient base, cnclaser:CNC or Laser cut]
// X dimension. grid units (multiples of 42mm) or mm.
Width = [3, 0]; //0.1
// Y dimension. grid units (multiples of 42mm) or mm.
Depth = [2, 0]; //0.1
oversize_method = "fill"; //[crop, fill]
position_fill_grid_x = "near";//[near:"← left", center:"↔ center", far:"→ right"]
position_fill_grid_y = "near";//[far:"↑ up", center:"↕ center", near:"↓ bottom"]
// X outer dimension. grid units (multiples of 42mm) or mm.
outer_Width = [0, 0]; //0.1
// Y outer dimension. grid units (multiples of 42mm) or mm.
outer_Depth = [0, 0]; //0.1
// z outer dimension. mm.
outer_Height = 0; //0.1
position_grid_in_outer_x = "center";//[near:"← left", center:"↔ center", far:"→ right"]
position_grid_in_outer_y = "center";//[far:"↑ up", center:"↕ center", near:"↓ bottom"]
//Reduce the frame wall size to this value
Reduced_Wall_Height = -1; //0.1
Reduced_Wall_Taper = false;
plate_corner_radius = 3.75; //0.01
//Corner radius for the inner corners (Works well with build_plate_enabled)
secondary_corner_radius = 3.75; //0.01

/* [Printer bed options] */
build_plate_enabled = "disabled";//[disabled, enabled, unique]
//spread out the plates, use if last row is small.
average_plate_sizes = false;
//Will split the plate in to the
build_plate_size = [200,250];

/* [Base Plate Options] */
// Enable magnets in the bin corner
Enable_Magnets = false;
//size of magnet, diameter and height. Zacks original used 6.5 and 2.4
Magnet_Size = [6.5, 2.4];  // .1
//raises the magnet, and creates a floor (for gluing)
Magnet_Z_Offset = 0;  // .1
//raises the magnet, and creates a ceiling to capture the magnet
Magnet_Top_Cover = 0;  // .1
// [Magnet Release Options]
// Method to help remove magnets: "none", "slot" (side pry), "hole" (poke from behind)
Magnet_Release_Method = "none"; //[none, slot, hole]
//Enable screws in the bin corner under the magnets
Corner_Screw_Enabled = false;
//Enable hold down screw in the center
Center_Screw_Enabled = false;
//Enable cavity to place frame weights
Enable_Weight = false;
//Removes the bottom taper
Remove_Bottom_Taper = false;

/* [Base Plate Clips]*/
Connector_Only = false;
Connector_Position = "center_wall"; //["center_wall","intersection","both"]

Connector_Clip_Enabled = false;
Connector_Clip_Size = 10;
Connector_Clip_Tolerance = 0.1;

//This feature is not yet finalised, or working properly.
Connector_Butterfly_Enabled = false;
Connector_Butterfly_Size = [5,4,1.5];
Connector_Butterfly_Radius = 0.1;
Connector_Butterfly_Tolerance = 0.1;

//This feature is not yet finalised, or working properly.
Connector_Filament_Enabled = false;
Connector_Filament_Diameter = 2;
Connector_Filament_Length = 8;

//This feature is not yet finalised, or working properly.
Connector_Snaps_Enabled = "disabled"; //["disabled","larger","smaller"]
Connector_Snaps_Clearance = 0.2;

/* [Custom Grid]*/
//Enable custom grid, you will configure this in the (Lid not supported)
Custom_Grid_Enabled = false;

//Custom gid sizes
//I am not sure it this is really useful, but its possible, so here we are.
//0:off the cell is off
//1:on the cell is on and all corners are rounded
//2-16, are bitwise values used to calculate what corners should be rounded, you need to subtract 2 from the value for the bitwise logic (so it does not clash with 0 and 1).
//[c,[x,y]], c corner value as shown above. [x,y] x and y size of the cell.
xpos1 = [3,[2,[3,3]],0,0,2,4,0];
xpos2 = [2,0,0,0,2,2,0];
xpos3 = [2,0,0,0,2,2,0];
xpos4 = [2,2,2,2,2,2,0];
xpos5 = [6,2,2,2,2,10,0];
xpos6 = [0,0,0,0,0,0,0];
xpos7 = [0,0,0,0,0,0,0];

/* [Model detail] */
//Work in progress,  Modify the default grid size. Will break compatibility
pitch = [42,42,7];  //[0:1:9999]
// minimum angle for a fragment (fragments = 360/fa).  Low is more fragments
fa = 6;
// minimum size of a fragment.  Low is more fragments
fs = 0.1;
// number of fragments, overrides $fa and $fs
fn = 0;

/* [debug] */
Render_Position = "center"; //[default,center,zero]
// Debug slice
cut = [0,0,0]; //0.1
// enable loging of help messages during render.
enable_help = false;

/* [Hidden] */
module end_of_customizer_opts() {}

//Some online generators do not like direct setting of fa,fs,fn
$fa = fa;
$fs = fs;
$fn = fn;

function round_half_down(number, max_allowed) =
let (up = ceil(number), down = floor(number),
    result = (number - down <= 0.5 || up > max_allowed) ? down : up)
  echo("round_half_down", number=number, up=up, down=down, max_allowed=max_allowed, result=result, lessthan=number - down <= 0.5, upgreater=up > max_allowed)
  result;

function split_dimension(
    gf_size,                // The size of the grid (inner dimension of the grid area)
    gf_outer_size,          // The outer bounding size (outer dimension of the grid area)
    plate_size,           // The size of each plate or segment to split into
    position_fill_grid, //grid_alignment,         // Alignment of the grid within the bounding area ("near", "center", "far")
    position_grid_in_outer, //bounding_alignment,     // Alignment of the bounding area relative to the grid ("near", "center", "far")
    average_plate_sizes = false // Whether to average the sizes of the segments
) =
  assert(is_num(gf_size), "gf_size must be a number")
  assert(is_num(gf_outer_size), "gf_outer_size must be a number")
  assert(is_num(plate_size), "plate_size must be a number")
  assert(is_string(position_fill_grid), "position_fill_grid must be a string")
  assert(is_string(position_grid_in_outer), "position_grid_in_outer must be a string")
  let(
    // Determine the larger size between gf_size and gf_outer_size
    totalOuterSize = gf_outer_size > gf_size ? gf_outer_size : gf_size,
    outerPadding = max(0, totalOuterSize - gf_size),

    // Calculate offsets based on position,
    //only used on first plate
    outerPrefix =
      position_grid_in_outer == "far" ? outerPadding :
      position_grid_in_outer == "center" ? outerPadding/2 : 0,
    gridPrefix=
      position_fill_grid == "near" ? gf_size - floor(gf_size) :
      position_fill_grid == "center" ? (gf_size - floor(gf_size))/2 : 0,

    // Calculate the number of plates and average sizes
    platesRemaining = ceil(totalOuterSize/plate_size),
    avgOuter = platesRemaining > 1 && average_plate_sizes ? totalOuterSize/platesRemaining : plate_size,
    //avgSize = platesRemaining > 1 && average_plate_sizes ? gf_size/platesRemaining : plate_size,
    max_allowed_grid_size = min(gf_size, plate_size-outerPrefix),

    // Calculate the size and outer size for the this plate
    current_grid_size = totalOuterSize <= plate_size
      ? gf_size
      : gridPrefix + max(0, round_half_down(min(gf_size, avgOuter-outerPrefix-gridPrefix), max_allowed =plate_size-outerPrefix-gridPrefix)),
    current_outer_size = totalOuterSize <= plate_size
      ? totalOuterSize
      : current_grid_size + outerPrefix,

    // Calculate the remaining size and outer size
    remSize = max(0, gf_size - current_grid_size),
    remOuter = max(0, totalOuterSize - current_outer_size)
  )
  echo("🟪split_dimension", gf_size=gf_size, position_fill_grid=position_fill_grid, plate_size=plate_size, platesRemaining=platesRemaining, gridPrefix=gridPrefix, current_grid_size=current_grid_size, remSize=remSize, max_allowed_grid_size=max_allowed_grid_size)
  echo("split_dimension", gf_outer_size=gf_outer_size, position_grid_in_outer=position_grid_in_outer, plate_size=plate_size, platesRemaining=platesRemaining, avgOuter=avgOuter, outerPrefix=outerPrefix, current_outer_size=current_outer_size, remOuter=remOuter)
  assert(current_outer_size > 0)
  let(
    next = remSize > 0 || remOuter > 0 ? split_dimension(remSize, remOuter, plate_size, "far", "near", average_plate_sizes): [],
    posOuter = position_grid_in_outer == "center" && totalOuterSize > plate_size ? "far" : position_grid_in_outer,
    posGrid =  position_fill_grid == "center" && gf_size > plate_size ? "near" : position_fill_grid
  )
  echo("split_dimension", next=next, posOuter=posOuter, posGrid=posGrid, current_grid_size=current_grid_size, current_outer_size=current_outer_size)
  concat([[current_grid_size, posGrid, current_outer_size <= current_grid_size ? 0 : current_outer_size, posOuter]], next);
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

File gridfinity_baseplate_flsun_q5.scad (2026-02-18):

// include instead of use, so we get the pitch
include <modules/gridfinity_constants.scad>
use <modules/module_gridfinity_baseplate_common.scad>

ear_hole_x = 182.5; // distance between existing screw holes on FLSUN q5.
ear_hole_y = 7; // distance of screw hole from the front panel.
cube_z = 4.4; // ht from above.
M4_d = 4.2; // diameter needed for an M4 bolt.

wallThickness = 0.2; //Extend and imbed in to wall to fit around corner

/* [Hidden] */
module end_of_customizer_opts() {}

from_ends = (ear_hole_x - gf_pitch*4) / 2;

union(){
  frame_plain(4, 1, height = cube_z);

  for (i = [0,1]) {
    x = i * ear_hole_x - from_ends-wallThickness;
    difference() {
      hull() {
        translate([x, ear_hole_y, 0])
          cylinder(h=cube_z, d=M4_d*2, $fn=20);
        translate([x - from_ends * i, ear_hole_y - M4_d, 0])
          cube([from_ends+wallThickness, M4_d*2, cube_z]);
      }
        translate([x, ear_hole_y, -0.01])
          cylinder(h=cube_z + 0.02, d=M4_d, $fn=20);
    }
  }
}

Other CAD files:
gridfinity_basic_cup.scad
combined/gridfinity_baseplate.scad
combined/gridfinity_baseplate_flsun_q5.scad
combined/gridfinity_basic_cup.scad
combined/gridfinity_bin_removable_walls.scad
combined/gridfinity_chess.scad
combined/gridfinity_drawers.scad
combined/gridfinity_glue_stick.scad
combined/gridfinity_item_holder.scad
combined/gridfinity_lid.scad
combined/gridfinity_marble.scad
combined/gridfinity_sieve.scad
combined/gridfinity_silverware.scad
combined/gridfinity_silverware_legacy.scad
combined/gridfinity_sliding_lid.scad
combined/gridfinity_socket_holder.scad
combined/gridfinity_tray.scad
combined/gridfinity_vertical_divider.scad
combined/stanley_basic_cup.scad
demos/gridfinity_baseplate_demo.scad
demos/gridfinity_basic_cup_demo.scad
demos/gridfinity_drawer_demo.scad
demos/gridfinity_item_holder_demo.scad
demos/gridfinity_tray_demo.scad
demos/module_brick_pattern_test.scad
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

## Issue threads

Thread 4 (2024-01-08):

Wall pattern does not apply to dividers.

brotherssmith, 2024-01-08:
I don't see the setting listed in the documentation, but there is a checkbox in the program, and it seems to do nothing. Have tried changing various wall pattern and divider settings to no effect.

Unrelated - also having the missing variables issue for baseplate generation, restoring the old variable names remedied some issues, but the missing Sdix remains for me, and it won't generate a full grid unless in baseplate also a lid mode.

Feature request - A baseplate/lid that is a "lite" version, missing magnet holes for efficiency.
Example here - https://www.thingiverse.com/thing:5975756

Thanks for all the work you've put into this already.

ostat, 2024-01-10:
>I don't see the setting listed in the documentation, but there is a checkbox in the program, and it seems to do nothing. Have tried changing various wall pattern and divider settings to no effect.
This was a bug introduced when I rewrote the new divider logic. Its been fixed, but its only setup to work for the **Vertical chambers** option at the moment.
fixed in e16e486
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

>Unrelated - also having the missing variables issue for baseplate generation, restoring the old variable names remedied some issues, but the missing Sdix remains for me, and it won't generate a full grid unless in baseplate also a lid mode.
I believe this was covered in #1, its fixed now

>Feature request - A baseplate/lid that is a "lite" version, missing magnet holes for efficiency.
>Example here - https://www.thingiverse.com/thing:5975756
Moved out to its own issue. #5

natalietrinh102, 2024-05-22:
Are there plans to support horizontal dividers? Only supporting vertical dividers leads to some odd label positioning.

ostat, 2024-05-22:
> Are there plans to support horizontal dividers? Only supporting vertical dividers leads to some odd label positioning.

We do support horizontal dividers. However we don't support the patterned wall on horizontal dividers. This is beachside I would need to deal with the intersection area when both are enabled.
Not sure I follow how this impacts the labels?

natalietrinh102, 2024-05-24:
I meant support for patterned walls on horizontal dividers. The labels positions currently don't allow for you to build a model with the label on the short side while having a patterned wall:

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
This is what I'm intending to do - with a patterned wall in the middle

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
This is the orientation that allows for a patterned wall - but the label is now on a side that I won't use. (There is also some odd geometry on vertical chamber in this case)

For now I've just exported it into a CAD program and created the pattern myself, but adding it would be useful for me in the future.

ostat, 2024-05-24:
We can do that.

ostat, 2024-05-25:
Fixed in e92073d .

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

ostat, 2024-06-10:
this issue is resolved

Closed 2024-06-10.

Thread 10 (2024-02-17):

[BUG] Drawers do not have boxes.

Monniasza, 2024-02-17:
When I enable baseplates on the drawer, the drawer does not have the bottom base, but throws a warning: `Ignoring unknown module 'grid_block'`. Please revert the base STL and my work workaround with tiling the base model. Also please merge the efficient shelves that I've made after you merged the PR.

ostat, 2024-02-17:
This should be fixed. Can you get latest and let me know if you are still having issues?
I also added some filament saving options to the walls. Feedback welcome.
I would like to avoid requiring the STL unless we absolutely need to. As it reduces the options, like setting the base to half pitch.
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

Monniasza, 2024-02-17:
It's okay. I'll check out the options. I'm using OpenSCAD version 2023.08.29 snapshot.

Monniasza, 2024-02-17:
The pattern extends past the front and starts too far to the front.
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

Monniasza, 2024-02-17:
Here are my settings:
[gridfinity_drawers.json](https://github.com/ostat/gridfinity_extended_openscad/files/14319404/gridfinity_drawers.json)

Monniasza, 2024-02-17:
On the left side of the drawer on the rear there should not be hex pattern.
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

ostat, 2024-02-17:
I will take a look. I had shift the side cutout to stop it going out the back.

Good spot re the back will verify the math.

Not sure if you saw, I added an option to the drawers to remove the floor and just have the grid. If you fill it with bins you might not need the solid floor. Need to check if the bins would stick through and mess up the sliding action.

ostat, 2024-02-17:
The wall coutout positioning is fixed in d64e655

Monniasza, 2024-02-18:
@ostat The wall cutout positioning looks good.
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

Monniasza, 2024-02-18:
However, the model with hex pattern takes forever to slice on PHOEU computer.

ostat, 2024-02-19:
I updated the model to allow for custom drawer sizer. It was more complex than expected, but I think I got there in the end. Would appreciate if you could review the changes in case I broke anything.
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

Monniasza, 2024-02-19:
I get lots of warnings and the drawer boxes do not appear, only the handles.
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
https://gist.github.com/Monniasza/8cce959ca7d661030b4a5329b9eec068

Monniasza, 2024-02-19:
Additionally, the drawerslides should only extend so far as the user has defined, but they always cover the entire width of the chest.

Monniasza, 2024-02-19:
You can define the inner dimensions of the drawers as a list.

ostat, 2024-02-19:
Sorry had not pushed all the changes. Think I got them all now.

Monniasza, 2024-02-19:
@ostat You have not said that setting drawer handle height to -1 makes it span the entire drawer height.

Monniasza, 2024-02-19:
Vertical handles do not require supports, unlike horizontal handles.

ostat, 2024-02-19:
We can prob close this now? I think all the issues are resolved.

I have a couple of other ideas.

I would like an option to swap drawers around when they are not the same size. Perhaps a small set (every 7mm) of runners that slides in to the walls of the drawer or chest? Though I'm a bit worried that the walls of the chest will flex too much.

Also I would like an option to have the chest fit in to the shape of a Gridfinity bin. But maybe this would need to be a different script, as it would confuse the settings.

Closed 2024-02-20.

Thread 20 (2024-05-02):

Support click lables

ostat, 2024-05-02:
Add support for - Gridfinity Swappable Labels by [Cullen J Webb](https://makerworld.com/en/@CullenJWebb)

https://makerworld.com/en/models/446624#profileId-353132

ostat, 2024-05-02:
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
[gridfinity_cup_modules_with_click_label.zip](https://github.com/ostat/gridfinity_extended_openscad/files/15187695/gridfinity_cup_modules_with_click_label.zip)

CullenJWebb, 2024-05-02:
I printed the test bin, thanks so much for adding this.

The labels fit well enough that I would consider it a success, but the dimensions are off by enough that the all important "click" isn't as satisfying. I've added the fusion360 files for both the bins and the labels, but here are the dimensions for reference:

-  Rib z height: 0.6mm
-  Rib X width at top: 1.3mm
-  Rib X width at bottom: 0.8mm

ostat, 2024-05-02:
I will try to adjust the ribs. I did them in a lazy way that is not very accurate. I will fix that up with more exact dimensions.

zerocle, 2024-05-31:
I commented on MakerWorld, but figure this is probably the better place. First, these bins and labels are amazing, so thank you for adding support for the click labels. There are a couple of bugs I noticed,

1. if the bin's split line intersects with the snap label, then the split will raise above the top of the label, interfering with the label placement
2. if you extend the label to take up multiple widths, only the first width of label gets the snaps embedded.

For reference my settings that I changed were
- width: 5
- vertical chambers: 5
- label style: click
- label width: 3

ostat, 2024-06-02:
@zerocle, Thanks for reporting. That is correct, there are a few complexities I need to resolve with the click labels.

The dividers is a bit tricky due to how I have written the code. (I would need to subtract the label from the divider, then subtract the label with click option from the bin space). One easy option might be to add a divider height option. This will allow the divider to be to be reduced below the click label height so it does not interfere. This might also be helpful for other situations.

Adding the click to other labels is something I have been meaning to do. I need to work out what to do if the label is not big enough to fit a standard click label. Perhaps @CullenJWebb has some ideas there?

CullenJWebb, 2024-06-03:
@ostat - The click labels standard will always be the same size, however, I do think I have a solution for undersized space for labels.

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

Here you can see that I've generated a bin with a label space of only 0.6u wide, whereas the click labels require at least 0.97u or something like that. I've added the click label slot negative volume and attached it over-hanging the edge.

When sliced it looks like this:

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

There are 2 ribs remaining to click into, with space for the label to overhang the edge. This gives users the option to manually trim their labels in the slicer or with scissors irl, or even let them hang over the edge. The over-hang isn't required though and if it's easier to you to simply trim off the right edge that would be fine as well.

So here are my suggestions:

- Allow for under-sized label slots, preferably by leaving an overhang for easier trimming
- Default to left-aligned slots and trim from the right side. All pre-generated labels place the size text on the left which is most likely to be the purpose of multiple smaller labels in a bin (multiple sized components).
- In the case of right aligned labels being selected then of course trim from the left side, the user will need to generate their own labels with right-aligned text (for now, if multiple people need something like this I would write a script to generate these as well)

**In short, I don't want to define a specific size for "mini" labels as we will always run into unique situations where somebody would prefer a larger or smaller label, and simply allowing them to trim to fit resolves all use cases for less than 1u width.**

Also, as I mentioned to zerocle on Makerworld, I like the idea of multiple label slots per bin, especially full width label slots. I've attached screenshots here showing how I added 3 label slots to a 3u wide bin using the negative volumes again.

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

That is the negative volumes being positioned, here is the sliced model:

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

ostat, 2024-06-04:
@CullenJWebb Some good ideas there. I will have a look and see what I can come up with. I think we can make some of that work.

One thought, The click labels hold in place using the triangle ribs. Did you consider instead integrating the click mechanism in to the long sides of the label? This should allow for a very similar click function without the need for the rib. Making the creating short and long label slots a lot easier.
For a bin that was say three units wide, you could just have a single long slot along the label and someone could insert the click labels are they want.

CullenJWebb, 2024-06-04:
@ostat Dang, that's a great idea. I will do some testing to see how well that works. I don't want to deprecate all of the bins people have already created so I need to be sure that this would be a worthwhile improvement with no downsides. I'll follow up with you on that.

CullenJWebb, 2024-07-05:
I am discussing the change of the click label standard with [ndevenish of gflabel](https://github.com/ndevenish/gflabel/issues/7). Feel free to add any thoughts you may have in that discussion, otherwise thank you for your patience while I redesign it.

Also, in case you are still working on implementing it, the name is going to be changed shortly to "Cullenect" labels to help differentiate the click labels from the click baseplates and lids already in the gridfinity ecosystem.

CullenJWebb, 2024-10-21:
@ostat The 2.0 version of the labels are ready here: https://github.com/CullenJWebb/Cullenect-Labels

They are being renamed "Cullenect" to differentiate between other swappable label types. Here are some of the features:

- Backward compatible with v1 bins (when generating 1u width labels)
- Variable label width
- Simpler geometry, easier to print and model.
- Emboss or deboss text
- More satisfying click
- Labels smaller than the socket can slide left and right along the new rail socket design
- Better vertical slot

And best of all it's been designed in OpenSCAD so that basic labels can be generated by users. Icons are still difficult in OpenSCAD though so I'm going to help get this implemented in gflabel as well.

This is my first project in OpenSCAD so there are likely some rough edges. You may be able to import the cullenect_socket() and cullenect_socket_negative() functions to implement them into the bins, but you are no doubt much better at this than me and the geometry is simple enough with this new version.

ostat, 2024-10-21:
@CullenJWebb, awesome I will take a look as soon as I have time.

ostat, 2024-10-26:
Support has been added for version 2.
I need to improve the alignment logic (for all the label sockets) as the first cell has different alignment needs than the second and so on.
For Cullenect V2, I think the most compatible approach is to have the socket be the full width of the label/bin.
@CullenJWebb, feedback welcome.

6072379

klingac, 2024-12-01:
Hi @ostat. I wanted to use those new Cullenect V2 labels, but it seems that they are not working with default options. See example in the picture
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
It looks like the label is "leaking" to bin's walls.

CullenJWebb, 2024-12-03:
@klingac I recommend using the negative volume provided by the Cullenect scad while this is being implemented. Once you've created the label you want you can also generate a negative volume and in your slicer position that where the label will go and you can customize any bin this way.
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
ostat, 2024-12-06:
Labels are a bit of a mess at the moment.  Trying to make it possible to support all options with out glitching.

I am not sure how to get the width of the label to be correct for all scenarios.
I have also not updated to use your latest changes after the first release. I might have a chat to you about some tweaks to the function. I think I had to make some changes to bring it in. It would be handy if we could copy the function with no changes so its easier to keep it up-to date with any changes you make going FW.

CullenJWebb, 2024-12-15:
I'm working on the script still to add vertical socket generation (not relevant to your library) and while I'm in there I'll work on making the function more independent. I'll make is so that you pass the dimensions to it directly rather than a global variable.

ostat, 2025-01-24:
I have pushed a fix to better support V1 and V2.

@CullenJWebb, Feedback is welcome.

I struggled to make the standard sizes fit. Ideally the default size should be about 34mm, 36mm makes it a very
**V2**
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

**V1**
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

CullenJWebb, 2025-01-29:
This works very well. I realize that the labels are a tight fit and I apologize for the trouble that's caused. The original spec was based on the bins generated with the Fusion360 plugin and the stackable rims on those are very different from vanilla Gridfinity. I would consider changing the spec but that would make V1 bins incompatible with V2 labels, not to mention everyone who has already printed V2 bins.

I've created a pull request here to auto calculate the width of the Cullenect sockets to spec unless the user specifies a size: https://github.com/ostat/gridfinity_extended_openscad/pull/115

I really like the solution you came up with to extrude above the label for clearance. It's not visible in the models that I printed and it looks very clean.

Labels snap in satisfyingly and I can configure many different bin/label configurations without any apparent bugs. I think that this is a solid and complete implementation.

ostat, 2025-01-29:
The print looks good. Thanks for testing.

I think the change is fine, will accept later.

I do have a concern with the widths. People need a way to create the right sized label for the bin/label size.
This gets a bit tricky.
If the bin is 3 units wide, split in two chambers with labels what size label should they make?
I can output the size to the console on OpenSCAD,
But that won't help people that use web generators or download pre generated models.

If the bin/label side is 1unit then we can use a fixed set size to match the specification.
With version 2 this is less of an issue. Im not sure the best solution.

CullenJWebb, 2025-01-29:
A single full width label socket is the solution. I've actually already printed test pieces and it works very well, I'll upload pictures later.

It's oddly satisfying to slide the labels left and right inside the socket before adding other labels. Not useful, but satisfying.

CullenJWebb, 2025-01-29:
People can generate labels of any width they want and can throw the spec out the window. But combining labels of multiple units, even mixed units, works very well. A 6mm spacer is optional but it fills the gap created by the spec.

Combining 2 labels will have 1 gap to fill, combining 3 labels will have 2, and so on.

Here's what that looks like. I printed fitment tests for a 3u and 2u wide socket:

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

bmatheny, 2025-02-07:
I know there's still some work to be done, but I appreciate you all volunteering your time and working on this. I had been using the old V1 labels for a while (via gflabel) and the V2 changes address a lot of the annoyances I had. I'm looking forward to this getting finalized in extended, so I can start generating new bins with the right set of labels.

Anyhow, thank you both for putting your time in on this.

ostat, 2025-02-19:
@CullenJWebb and others,
Are we happy with the changes? Do we think we can close this now?
Of cause we can always, create new tickets if we find issues.

CullenJWebb, 2025-02-25:
@ostat I believe so, it's been working well for me and I agree that any future bugs should have their own ticket.

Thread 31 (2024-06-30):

Magnet stress and removal groove

BreakMate, 2024-06-30:
I just want to start by saying, WOW! This resource is amazing for making custom gridfinity bins.

I wanted to request making a small addition to the magnet holes. If there is a small enough groove, this would allow for easier insertion and removal of the magnets. This can be applied to both the bins as well as the base, although I havent tested it with the base. I would add them myself, but I am horrid with openscad, but I was able to test this in Freecad with great success. Could you add a parameter to implement this?
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

ostat, 2024-06-30:
This is an interesting idea. I'm sure it can be added.
Do you think we could angle it in to the corner?
My reason is the efficient bases. Those support magnets and have a cap that goes over the magnet. If we angle it in to the corner we won't need to change the cap.

BreakMate, 2024-07-01:
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

Good point! And quite a good feature, the efficient floor. I redrew the gaps and it still works! I made the straight part 1.5mm and the diameter of the groove 1.3mm. The magnets are 6mm and I made the holes in my model 6mm

BreakMate, 2024-07-01:
Using Prusaslicer to slice, MK4 with a 0.4 nozzle to print.

My initial reason for avoiding the outer corners was to reduce the chance of curling on the edges

ostat, 2024-07-01:
That looks good. Nice work getting it printed so fast.
I agree that pointing to the centre would be more stable.
I could direction it based on the selected floor type, efficient floors to the corner and smaller, otherwise to the centre and a bit bigger.
Do you have thoughts on the relief size for different sized magnets?

BreakMate, 2024-07-01:
I do notice in your parameters, there is a hard cutoff of how close the magnets can get to the side of the base. not sure what that value is, but could be worked around.
If the magnets get smaller, then maybe it would hold better if the groove shrinks slightly. Making it too small would make it more difficult to fish it out (in the picture you can see the pick I'm using). Shouldn't be too big of an issue

If the efficient floor would account for the groove towards the center, I think that might work out the best and reduce the chance of curling.

BreakMate, 2024-07-01:
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

I love the efficient floor still able to use magnets, but I cant get them out now LOL

ostat, 2024-07-01:
I had a quick go at this tonight.
I am bit sick so it needs a bit of work to get it working better and covering different sized magnets better. Also I have not tired to print this.

The code is pushed to the main branch.

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

BreakMate, 2024-07-01:
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
It works swell!
I printed this with PETG in an enclosure. I've found that all gridfinity bins print better in an enclosure. It practically eliminates all warping. The black one I printed earlier I printed with PLA without an enclosure and the house fan was running, minor warping but enough to notice.

ostat, 2024-07-02:
Couple of questions;
Do you think this is good to close?

Based on your testing what are the recommend settings with the relief on and off?
The original design was to use 6.5mm diameter for a 6mm magnet, we add 0.1mm to the depth.
I would like to document recommendations for people.
Are the magnets sitting prod, in that image, do we need to recommend adding some extra depth for sagging of the bridge?

BreakMate, 2024-07-03:
I have never thought that 6.5mm was good for 6mm magnets (unless you mean for glue). When there are just magnet holes, 6.1 seems to do the trick. Thanks to this relief, I can make the magnet holes exactly 6 millimeters. It goes in with pressure, so I know that it won't come out easily.

As for the magnet protrusions, I believe that part of the problem comes from the efficient floor. The flex that is generated when trying to push in the magnets is causing them not to fully seat the first time around. Pressure must be applied from both sides. I haven't tested this with PLA, only PETG.

Magnet depth must be controlled by the user. I personally like 2.4 millimeters depth for a 2 millimeter magnet, probably due to overhangs. If overhangs are to be avoided, maybe add a version of the overhang remedy that only is meant to make bridges without necessarily making a hole.

Im in vegas currently, will be back thursday for more printed tests.

BreakMate, 2024-07-09:
Ok, so I found out that my magnets are actually 2.2 mm, so makes sense why 2.4mm height always worked well for me.

BreakMate, 2024-07-10:
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

It is kinda thin, maybe 1~2 more layers would be better

ostat, 2024-07-10:
That should be configurable as the floor thickness. Do you know what value was used? I would double check see if there are any bugs in the floor thickness and the clearance height calculations.

rwgunther, 2024-07-19:
I'm experiencing adhesion problems with the grooves pointing out to the corners. I have to use brims to print these without the corners curling. I don't seem to experience that as much when I don't include the grooves, but I definitely like having them!

ostat, 2024-07-27:
@rwgunther, I have change the `magnet release` option from a boolean (on/off) to a dropdown where you can select if you want the relief to point in or out. I think pointing in should resolve the adhesion issue you were having? Please let me know how it goes if you test it.
`Auto`, will point out for `efficient floor = on`, and in for `efficient floor = off`.

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

rwgunther, 2024-07-28:
This looks great. I'll try it out on my next print!

ostat, 2024-08-06:
Close as I think this is good now.

Closed 2024-08-06.

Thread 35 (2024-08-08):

please add fractional bases

ostat, 2024-08-08:
https://www.printables.com/model/630057-gridfinity-extended-openscad/comments/1975992

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

Andor, 2024-08-10:
Also, if I switch between "crop" and "fill" axis switches between length/width:
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

jziolkowski, 2024-11-21:
I was about to post the same request. Maybe it would be enough to "just" add "close" mode to oversize option, so that the last grid is properly closed, at whatever size it is? That will make a banger feature to use up these very last mm's of a drawer.

ostat, 2024-11-22:
This is now supported, I rewrote the base generator, so its more flexible.
I still need to do more testing.
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

jziolkowski, 2024-11-22:
OMG! I'll test later in the evening and will report back! Thanks!

jziolkowski, 2024-11-22:
I just cloned the repo. Also just installed openscad nightly.

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

So there is something still needed.

jziolkowski, 2024-11-22:
Oh wow, that's awesome! I was about to post that it still doesn't work, but it simply needs "fill" method. Amazing work, thanks A LOT!

ostat, 2024-11-23:
I should change the default.

jziolkowski, 2024-11-23:
Got another idea/request.

In short, expanding of the "center grid functionality" so that I would be able to input some arbitrary size, that will be used to center the generated grid. Gridfinity rebuilt has this as "minimum grid size" and has the option to either center on that size, or to even align to either corner(s). Then, whatever the calculated grid size is (including the fractional grids), one would be able to additionally put the entire plate on an arbitrary size.

Practical example:

my drawer fits 7.5 x 9 grids, but there is still some free space left. There is no point in having a 7.586 fractional grid due to compatibility with the rest of the system, so that remaining "wasted" space could be filled with plastic so that it won't require glueing/screwing to the bottom of the drawer.

ostat, 2024-11-23:
So having the outer plate size be different from the grid size. I can take a look. I think you would need two options, the outer size and the alignment.

Wouldn't it be just as effective to let the grid go to the end? You then have the option to fill the space with partial cups if you want.
In your example the end cup could be x.586 units wide.

jziolkowski, 2024-11-23:
I would still prefer to have fractional grids/cups to .5 only, as that way it all maintains compatibility with everything (I really like the cup feature of having the bottom divided into 1/4ths)

Despite that drawer having dimensions I want to utilize to the max, having very odd sized grids would only work in the context of that drawer, and I want to have the cups interchangeable everywhere.

ostat, 2024-11-25:
This has been added
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

ostat, 2024-11-25:
You have the option to centre  or not the padding and center or not the grid.

So if I'm not mistaken for the example you have shown, you would create a 3 x 3 with a larger outer size not centred, then create a 4 x 3 also not centred.
I think this can do that example. Did you pull it down and give it a try?

jziolkowski, 2024-11-25:
Yes, I have the latest pull. I disabled the center option for the outer dimension (tho it doesn't seem to do much)

These are my options:
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

I need that padding added on top of the plate, not on the bottom.

ostat, 2024-11-25:
I see what you mean, I believe you can achieve that by switching your x and y.

I am hesitant to increase the complexity where not needed.
As much as I like the bit wise logic it's too complicated for people to use.

jziolkowski, 2024-11-25:
Ok, swapping X/Y does the trick. But maybe instead of the bitwise approach, you could change "center grid in outer <X> / <Y>" to "Outer <X> / <Y> alignment" with a dropdown "Left/Center/Right"

Then it could be aligned in every orientation and arguably easy to grasp to users

jziolkowski, 2024-11-25:
BTW did you consider other donation providers? Current paypal rates are borderline criminal.

jziolkowski, 2024-11-26:
This is awesome. Wow. Complete feature now :) Great job, thanks!

jziolkowski, 2024-11-26:
> BTW did you consider other donation methods? Current paypal rates are borderline criminal.

@ostat ^

ostat, 2024-11-27:
@jziolkowski, thanks for the offer but its ok, you don't need to donate. Hope you find the scripts helpful.

Closed 2024-11-26.

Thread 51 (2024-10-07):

1X1 Cup - Front missing

lsd87, 2024-10-07:
Using the basic cup (default design) and setting width X to 1.0 the front of the cup is missing, bit like having a wall cut out
Set the width to say 1.1 the front wall is correct.
Set the mm width to 42 the front wall is correct
Set the mm width to 41.9 the front wall has the hole so I assume when set to 1 unit there's a rounding down so less than 42mm but not sure why
Using with Openscad 2024.09.30

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

ostat, 2024-10-08:
This was a bug thanks for raising.
When the bin is smaller than 1 gf unit (42mm) the side lip is meant to be cut away to allow easier access to the bin.
A bug was introduced recently when I re-positioned the default location of the bin, resulting it it being off by 0.5 units (21mm)

fixed in 679f603

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

lsd87, 2024-10-08:
Hi Chris

Thanks for coming back, noticed that when selecting X 1.0 on the new version then there’s 2 cut-outs on the sides, set the size to 42mm they disappear

Also

I can raise an issue (if you want J) about the click label, they don’t fit – I think the recess is back to far.

Found the attached scad file from somewhere that works but does not have all the great options your version has

Thanks

Leigh

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

lsd87, 2024-10-08:
Bit of info -
If I change from the default to 1.0 using the down arrow button, at 1.0 you get the side notches.
Change to 1.1 with the up arrow, notches get removed, set back to 1.0 they return
Enter 1 manually and then click up (1.1) and then down back to 1.0 the notches do not appear.
Go down to (down arrow) 0.9, notches appear, go back up to 1.0 using up arrow they disappear
SO once you have set 1.0 manually it SCAD appears to remember its 1.0 and not 0.999999....

ostat, 2024-10-08:
That sounds about right. The error is a common programming _bug_ related to floating point numbers. Pressing the up or down arrow many times the error accumulates.
I could solve it in the script two ways.
- Round the number to two decimal places.
- apply the cutouts after 0.99 instead of 1.

I run into this type of error quite a bit in OpenSCAD, I always just ignore it as it's easy fixed. But it might be worth putting in a fix for others who might not realise the cause.

lsd87, 2024-10-09:
Looks like option 2  0.99 might be the easiest option

BTW. I assume the cuts are for getting your fingers in when you have a narrow cup

ostat, 2024-10-10:
I added rounding to dimensions that should fix the issue.
4dc4eb

Closed 2024-10-08.

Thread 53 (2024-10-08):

Click Labels do not fit

lsd87, 2024-10-08:
When printed the click/snap labels do not fit into the recess, It looks like the recess goes back to far.
Adjusting the zclearance does not help.

The Left cup is the current version, the right is the old version which works
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
The scad file below does work, I think its one of your older versions 17/2/2024

[gridfinity_basic_cup_simplified.zip](https://github.com/user-attachments/files/17292812/gridfinity_basic_cup_simplified.zip)

lsd87, 2024-10-08:
Bit of testing
If you set the lip style to reduced/minimum/not stackable then you can see the full recess, printed the not stackable version and the click/snap label fits fine.
Set to reduced lip and zone in
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
Then select normal and see the lip "eat" into the label platform at the back
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

lsd87, 2024-10-08:
A work around is to set the label depth to 16.5mm or more so that the curves of the back wall don't eat into the label recess.
Also setting zclearance to 1.0mm helps with stacking

lsd87, 2024-10-09:
I had a look at the old simplified SCAD cup that I printed and the whole label platform does not touch the inner edge lip because on the latest cups there's an extra lip I assume for better stacking.
So I printed another cup with the zclearance set to 3mm, this made the click label fit.
When label style is normal, the label relief can be used to lower the insert part of the platform but when click style is set, the relief setting does not work, that's why I had to use the zclearance

This is how the lip/platform connect with zclearance set to 0
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

And this is when its set to +3
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

The problem with labels is that there appears to be at least 4 types, I would like to use ndevenish great gflabel program so that I can make up any label I need without looking around the internet to see if someone else has created one using fusion/freecad ...etc
[https://github.com/ndevenish/gflabel#label-bases](url)

The pred labels don't appear to fit because the tabs need a slot in the cup edge to fit in (may be able to shrink using the --width option in gflabel), the predbox and plain might work but I liked the cullen/webb labels because they would be easy to change

I think its best to stick with the standard size (is there one) label initially. but with your version allows a user to adjust the width/size of the platform AND the recess. that way all variations could be covered.

As for click settings default
First does the zclearance just alter the location of the label platform ? if so, it needs to be under the Label settings section
Second can you put a note to say "if you use click, set zclearance to say 3mm" or something like it or
setting click sets the zclearance to +3 automatically

Sorry can't think of a good fix,  too many variables and I know nothing about SCAD

lsd87, 2024-10-09:
Sorry about the close/reopen, clicked on the wrong button hoh

lsd87, 2024-10-15:
I think the main problem is with the lip style
If the click recess is supposed to be 36.7mm, then using the normal lip, I read 36mm between the lip, therefore the click label will not fit. Same for the depth, 11.3 label won't fit in a 10mm recess.
Its either not use the normal lip or move the label platform down below the curved lip about 2mm or more zclearance

Normal lip
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

Reduced lip
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

Normal lip plus 2mm
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

BTW. Assume you know about the Line 177 error
[WARNING: variable extension_enabled not specified as parameter in file gridfinity_basic_cup.scad, line 177](https://github.com/ostat/gridfinity_extended_openscad/issues/177,D:/lsd/Downloads/gridfinity_extended_openscad-main%2015th%20Oct/gridfinity_extended_openscad-main/gridfinity_basic_cup.scad)
[WARNING: variable extension_tabs_enabled not specified as parameter in file gridfinity_basic_cup.scad, line 177](https://github.com/ostat/gridfinity_extended_openscad/issues/177,D:/lsd/Downloads/gridfinity_extended_openscad-main%2015th%20Oct/gridfinity_extended_openscad-main/gridfinity_basic_cup.scad)
[WARNING: variable extension_tab_size not specified as parameter in file gridfinity_basic_cup.scad, line 177](https://github.com/ostat/gridfinity_extended_openscad/issues/177,D:/lsd/Downloads/gridfinity_extended_openscad-main%2015th%20Oct/gridfinity_extended_openscad-main/gridfinity_basic_cup.scad)

lsd87, 2024-10-15:
I think using the gflabel program may be around the click label sizes since width and depth can be set so click (webb) default sizes can be over ridden.

usage: gflabel [-h] [--base {pred,plain,none,webb,predbox}] [--vscode] [-w WIDTH]
               [--height HEIGHT] [--depth DEPTH_MM] [--no-overheight] [-d DIVISIONS]
               [--font FONT]
               [--font-size-maximum FONT_SIZE_MAXIMUM | --font-size FONT_SIZE]
               [--font-style {regular,bold,italic}] [--margin MARGIN]
               [-o [OUTPUT ...]] [--style {embossed,debossed,embedded}]
               [--list-fragments] [--list-symbols] [--label-gap LABEL_GAP]
               [--column-gap COLUMN_GAP] [-v]
               LABEL [LABEL ...]

For me the various options are to
1). Drop the platform down when using click labels
2). I Gflabel set the sizes manually
3). Just use std labels and stick then in using double sided tape

The pret labels are 35.5mm long with 2 tabs making them 37.5mm long, would be nice to use them as well, would need a recess in the lip to take the two tabs - but this is a feature update :-)
https://www.printables.com/model/592545-gridfinity-bin-with-printable-label-by-pred-parame

ostat, 2024-10-15:
> BTW. could you make the click label "eat" into the lip like the pret ones ?
I am sure we could. however it would require reworking how the label is implemented, and is not an easy fix.
The label is subtracted from the cavity, and then the cavity is subtracted from the filled in bin.
This means even if the label extends past the cavity it cant interfere with the wall or the lip of the bin.
So we would need to find a clean way around this.

lsd87, 2024-10-17:
I've been playing with gflabel and the problem with the normal platform is that even lowering the platform down by say 3mm, the rear had the rounded edges at the corners. SO you have to resize the platform so the label to comes out away from the rounded corners, or cut the corners off the label
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

Using the click you have a square recess corners
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

Could you make the normal be like the click but without the 3 rails ?

CullenJWebb, 2024-10-21:
@ostat The 2.0 version of the labels are ready here: https://github.com/CullenJWebb/Cullenect-Labels

They are being renamed "Cullenect" to differentiate between other swappable label types. Here are some of the features:

- Backward compatible with v1 bins (when generating 1u width labels)
- Variable label width
- Simpler geometry, easier to print and model.
- Emboss or deboss text
- More satisfying click
- Labels smaller than the socket can slide left and right along the new rail socket design
- Better vertical slot

And best of all it's been designed in OpenSCAD so that basic labels can be generated by users. Icons are still difficult in OpenSCAD though so I'm going to help get this implemented in gflabel as well.

ostat, 2024-10-26:
I am going to close this ticket, as we have #20 still open that relates to adding support for the clicklabels

Closed 2024-10-26.

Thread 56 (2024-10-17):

Wall cutouts margin behavior not consistent with subdivisions

shrestha-pranav, 2024-10-17:
When creating a basic cup with wall cutouts, the internal dividers don't adhere to the global crop/space settings. For instance, with this hexgridrotated pattern, you can see some the internal dividers are cropped off with no margins at all, even though the outside walls have margins.
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

<details>
<summary> Parameter Set </summary>

```json
"example_bin": {
    "box_corner_attachments_only": "false",
    "cavity_floor_radius": "-1",
    "center_magnet_diameter": "0",
    "center_magnet_thickness": "0",
    "chamber_wall_thickness": "1.2",
    "chamber_wall_zClearance": "0",
    "cutx": "0",
    "cuty": "0",
    "depth": "[3, 0]",
    "efficient_floor": "smooth",
    "enable_help": "false",
    "extension_tab_size": "[10, 0, 0, 0]",
    "extension_tabs_enabled": "true",
    "extension_x_enabled": "disabled",
    "extension_x_position": "0.5",
    "extension_y_enabled": "disabled",
    "extension_y_position": "0.5",
    "filled_in": "disabled",
    "fingerslide": "none",
    "fingerslide_radius": "8",
    "fingerslide_walls": "[1, 0, 0, 0]",
    "flat_base": "false",
    "floor_thickness": "0.69999999999999996",
    "half_pitch": "false",
    "height": "[14, 0]",
    "hole_overhang_remedy": "2",
    "horizontal_chambers": "4",
    "horizontal_irregular_subdivisions": "false",
    "horizontal_separator_bend_angle": "0",
    "horizontal_separator_bend_position": "0",
    "horizontal_separator_bend_separation": "0",
    "horizontal_separator_config": "10.5|21|42|50|60",
    "horizontal_separator_cut_depth": "0",
    "label_position": "left",
    "label_relief": "0",
    "label_size": "[0, 14, 0, 0.6]",
    "label_style": "disabled",
    "label_walls": "[0, 1, 0, 0]",
    "lip_style": "normal",
    "magnet_diameter": "6.2000000000000002",
    "magnet_easy_release": "off",
    "position": "zero",
    "screw_depth": "6",
    "sliding_clearance": "0.10000000000000001",
    "sliding_lid_enabled": "false",
    "sliding_lid_thickness": "0",
    "sliding_min_support": "0",
    "sliding_min_wallThickness": "0",
    "spacer": "false",
    "tapered_corner": "none",
    "tapered_corner_size": "10",
    "tapered_setback": "-1",
    "vertical_chambers": "1",
    "vertical_irregular_subdivisions": "false",
    "vertical_separator_bend_angle": "0",
    "vertical_separator_bend_position": "0",
    "vertical_separator_bend_separation": "0",
    "vertical_separator_config": "10.5|21|42|50|60",
    "vertical_separator_cut_depth": "0",
    "wall_thickness": "1.2",
    "wallcutout_horizontal": "disabled",
    "wallcutout_horizontal_angle": "70",
    "wallcutout_horizontal_corner_radius": "5",
    "wallcutout_horizontal_height": "0",
    "wallcutout_horizontal_position": "-2",
    "wallcutout_horizontal_width": "0",
    "wallcutout_vertical": "enabled",
    "wallcutout_vertical_angle": "70",
    "wallcutout_vertical_corner_radius": "5",
    "wallcutout_vertical_height": "0",
    "wallcutout_vertical_position": "-2",
    "wallcutout_vertical_width": "0",
    "wallpattern_dividers_enabled": "horizontal",
    "wallpattern_enabled": "true",
    "wallpattern_fill": "crop",
    "wallpattern_hole_sides": "6",
    "wallpattern_hole_size": "5",
    "wallpattern_hole_spacing": "1.5",
    "wallpattern_style": "hexgridrotated",
    "wallpattern_voronoi_noise": "0.75",
    "wallpattern_voronoi_radius": "0.5",
    "wallpattern_walls": "[1, 1, 1, 1]",
    "width": "[2, 0]",
    "zClearance": "0"
}
```

</details>

Similar but separate issue: If the grid is taller than a certain size (with default wall_thickness=0), the dividers have a flat layer on the back of the grid pattern layer. Setting wall thickness to 1.2 fixes this issue (see sample parameters above). I believe this is because the wall cutout patterns have a default depth that is less than 1.6

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

ostat, 2024-10-17:
Thanks for raising. I kinda new it would be an issue, but knew it would be complicated so ignored it.
I had a go at fixing this, I don't think its right yet but its a start 11fd42b

shrestha-pranav, 2024-10-20:
That was fast, wow. This solves my issue! I should've waited a few days before printing my bins hah

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

For issue #2, if you set your height to >= 14 units, you will see a back wall on the dividers. Setting wall_thickness=1.20 will force thinner dividers (from default 1.60 I believe) and the back wall disappears (like in the first picture above)

<details>
<summary>Parameter set example for back wall issue </summary>

```json
"Cutout 2x3": {
    "box_corner_attachments_only": "false",
    "cavity_floor_radius": "-1",
    "center_magnet_diameter": "0",
    "center_magnet_thickness": "0",
    "chamber_wall_thickness": "1.2",
    "chamber_wall_zClearance": "0",
    "cutx": "0",
    "cuty": "0",
    "depth": "[3, 0]",
    "efficient_floor": "smooth",
    "enable_help": "false",
    "extension_tab_size": "[10, 0, 0, 0]",
    "extension_tabs_enabled": "true",
    "extension_x_enabled": "disabled",
    "extension_x_position": "0.5",
    "extension_y_enabled": "disabled",
    "extension_y_position": "0.5",
    "filled_in": "disabled",
    "fingerslide": "none",
    "fingerslide_radius": "8",
    "fingerslide_walls": "[1, 0, 0, 0]",
    "flat_base": "false",
    "floor_thickness": "0.69999999999999996",
    "half_pitch": "false",
    "height": "[14, 0]",
    "hole_overhang_remedy": "2",
    "horizontal_chambers": "4",
    "horizontal_irregular_subdivisions": "false",
    "horizontal_separator_bend_angle": "0",
    "horizontal_separator_bend_position": "0",
    "horizontal_separator_bend_separation": "0",
    "horizontal_separator_config": "10.5|21|42|50|60",
    "horizontal_separator_cut_depth": "0",
    "label_position": "left",
    "label_relief": "0",
    "label_size": "[0, 14, 0, 0.6]",
    "label_style": "disabled",
    "label_walls": "[0, 1, 0, 0]",
    "lip_style": "normal",
    "magnet_diameter": "6.2000000000000002",
    "magnet_easy_release": "off",
    "position": "zero",
    "screw_depth": "6",
    "sliding_clearance": "0.10000000000000001",
    "sliding_lid_enabled": "false",
    "sliding_lid_thickness": "0",
    "sliding_min_support": "0",
    "sliding_min_wallThickness": "0",
    "spacer": "false",
    "tapered_corner": "none",
    "tapered_corner_size": "10",
    "tapered_setback": "-1",
    "vertical_chambers": "1",
    "vertical_irregular_subdivisions": "false",
    "vertical_separator_bend_angle": "0",
    "vertical_separator_bend_position": "0",
    "vertical_separator_bend_separation": "0",
    "vertical_separator_config": "10.5|21|42|50|60",
    "vertical_separator_cut_depth": "0",
    "wall_thickness": "1.2",
    "wallcutout_horizontal": "disabled",
    "wallcutout_horizontal_angle": "70",
    "wallcutout_horizontal_corner_radius": "5",
    "wallcutout_horizontal_height": "0",
    "wallcutout_horizontal_position": "-2",
    "wallcutout_horizontal_width": "0",
    "wallcutout_vertical": "enabled",
    "wallcutout_vertical_angle": "70",
    "wallcutout_vertical_corner_radius": "5",
    "wallcutout_vertical_height": "0",
    "wallcutout_vertical_position": "-2",
    "wallcutout_vertical_width": "0",
    "wallpattern_dividers_enabled": "horizontal",
    "wallpattern_enabled": "true",
    "wallpattern_fill": "crop",
    "wallpattern_hole_sides": "6",
    "wallpattern_hole_size": "5",
    "wallpattern_hole_spacing": "1.5",
    "wallpattern_style": "hexgridrotated",
    "wallpattern_voronoi_noise": "0.75",
    "wallpattern_voronoi_radius": "0.5",
    "wallpattern_walls": "[1, 1, 1, 1]",
    "width": "[2, 0]",
    "zClearance": "0"
}
```

</details>

Backwall pictures:
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

ostat, 2024-10-26:
Thanks for posting the config.
I used your config, and believe this is fixed.
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

shrestha-pranav, 2024-11-07:
Looks great to me. Feel free to close the issue as fixed :)

Angle is good to me, I'd rather specify angle than have to calculate the lengths for this use case. In other use cases, length might make sense, although it's more of a convenience factor since they can be calculated either way.

ostat, 2024-11-08:
done

Closed 2024-11-08.

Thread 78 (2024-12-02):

Feature idea: grids connected on crossing

jziolkowski, 2024-12-02:
Basically what this guy did, but at normal gridfinity sizes

https://www.youtube.com/shorts/LLesH2ijoC0

jziolkowski, 2025-01-23:
yo this is awesome, i'll test later today when printing another drawer

does it also have the option to generate the clips?

ostat, 2025-01-23:
Yes, there is an option called, "**connectors only**"

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

ostat, 2025-01-23:
positioning the connectors on the cell side was simple, on the cell intersections was somewhat clunky. I position them pre cell, and cells share walls. I also dont want want clips on cells with padding or ones what are not full size.

then making it work for the printer bed splitting feature, for example

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

Anyway let me know your thoughts,

jziolkowski, 2025-02-04:
Ok that took a while, I was ill.

Anyway, these rock. Snapping is very tight, but when carefully using pliers or an edge of something hard it goes in very snugly. Printed with PLA and it didn't crack so that's nice, but I guess for mass production I'll go with PETG for the connectors.

If I'd be extra picky, if you could shave off like 0.5mm from the model on end, then it will give some breathing room for minor print inconsistencies.

Overall, A+++++

ostat, 2025-02-04:
Hi, thanks for testing the feature.
How did you find the bins sit? The first couple of tries I felt the clip was a little raised.

When you say from the connectors end do you mean the length? Meaning if you select 10mm, have the slot be 10mm wide and the connector be 9.5mm long?

There is a tolerance parameter for the clips, but I think it needs work. the tolerance increases the clearance in all dimensions including the length between the base plate and the clip.  Currently it affects both base plate and the clip. Which I am not sure about. Say you print a base with a 0.1 tolerance, then print some clips and tweak the tolerance to dial in the fit. When you go back to print more bases it will also use the new tolerance and the fit will be different.
I think the base should prob be fixed dimensions, and the tolerance should only impact the clip. I did it this was as the parts are quite thin shaving 0.5 off the wall of the clip makes it quite small, where 0.25 off both the base and the clip is not so bad.

jziolkowski, 2025-02-04:
For now I did not test your bins, I tested a 2x2 shallow 18650 holder (it weighs quite a lot with the accus, so that helped). I did not observe anything odd with fitting - I think why would it? The connectors sit flush with the top line of the grid and the outer cross section has the same shape as the grid.

One thing I did observe was that when I joined 4 grids with the center piece, they were buckled a bit, pulling upwards from the surface. In practice this is only noticeable when not under load. I will test that again but I will slightly stretch the center cross along X/Y so the fit is not as snug.

> When you say from the connectors end do you mean the length? Meaning if you select 10mm, have the slot be 10mm wide and the connector be 9.5mm long?

yes, trim them lengthwise for the straight connectors, and along X/Y for T/X connectors.

At the same time, maybe I need to tune the printer a bit more and adjust the print settings. For example I've noticed that when printing the grid it's better to move the seam to be not in the corner - when filament accumulates there it lowers the fitting tolerance.

Still, the initial test is 99% successful IMO. Knowing that after few days the grid will conform to the weight due to PLA characteristics I'm sure it will be flat :)

jziolkowski, 2025-02-04:
oh wait, my bad. I did test your bin. 2x1 with some PCBs inside. It sat well, no binding at all, and the expected wiggle room.

Monniasza, 2025-02-09:
@ostat It works, but it's little tight for me. I'll post a make on Printables soon.

ostat, 2025-02-09:
> @ostat It works, but it's little tight for me. I'll post a make on Printables soon.

Tonight to get the clip on or to tight to get the bin on the grid?

Monniasza, 2025-02-10:
@ostat It's tight both ways. Clip clearance chould be variable both between bins and grid and between grid and clip.

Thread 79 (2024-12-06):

Vertical Spacing with label shelf to low

MinchinWeb, 2024-12-06:
I've been playing with labels, particularly the legacy Cullenect labels. However, with the label shelf, the bins don't cleanly stack, even without a label installed. The missing clearance is small, probably under 0.5mm. It gets worse when a label is installed, as the default `gflabel` has a 0.4mm embossing (text height). Setting `z clearance` to 1.0 mm solves this, including when labels are installed. Should this z clearance become the default or otherwise added when a label (shelf) is printed?

This sample was printed with 0.2mm layers.

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

Zoomed in:

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

ostat, 2024-12-06:
Setting an auto min clearance of 1mm sounds like a good idea. Just need to check the impact.

ostat, 2025-02-23:
I know this is an old ticket. Sorry for the delay.

I have changed the default zClearance (renamed to headroom) to 0.8. I found this to be a good setting for my printer.
d5bf791

MinchinWeb, 2025-02-25:
Should do the trick!

Closed 2025-02-25.

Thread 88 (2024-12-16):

ItemHolder - Default gridfinity_item_holder.scad fails to render

flaviut, 2024-12-16:
Thank you for all your hard work on this, this project looks like it's going to save me a ton of time organizing my coffee supplies.

I ran into issues with the default uncustomized `gridfinity_item_holder.scad`. When I try and render it in openscad, I get the following errors and nothing shows up:

```
Parsing design (AST generation)...
Compiling design (CSG Tree generation)...
ECHO: "•••••• UB (USER library v2022) included! v.gd/ubaer  ••••••
• Version: β23.305 v [2024, 12, 15] • Design: 0
Layer: 0.08(24.37%) Nozzle ∅: 0.4 • fn:36 fs:0.75 fa:10 • Spiel: 0.2 •"
ECHO: "❌••••• Help off       use: helpsw=1;  •••••"
ECHO: "Schalter•
 messpunkt=🟢✔ • vp=❌ • anima=❌ • help=❌ • $info=🟢✔ • bed=❌ • hires=❌ •"
ECHO: "
---————————————————————————————————————————---
"
WARNING: Ignoring unknown variable 'magnet_diameter' in file gridfinity_item_holder.scad, line 606
WARNING: Ignoring unknown variable 'screw_depth' in file gridfinity_item_holder.scad, line 608
WARNING: Ignoring unknown variable 'center_magnet_diameter' in file gridfinity_item_holder.scad, line 609
WARNING: Ignoring unknown variable 'center_magnet_thickness' in file gridfinity_item_holder.scad, line 610
WARNING: undefined operation (undefined > number) in file gridfinity_item_holder.scad, line 695
WARNING: max() parameter could not be converted: argument 1: expected number, found undefined (undef) in file modules/functions_gridfinity.scad, line 40
WARNING: max() parameter could not be converted: argument 1: expected number, found undefined (undef) in file modules/functions_gridfinity.scad, line 40
WARNING: undefined operation (undefined + number) in file modules/functions_gridfinity.scad, line 43
WARNING: undefined operation (undefined + number) in file gridfinity_item_holder.scad, line 704
WARNING: undefined operation (undefined / number) in file gridfinity_item_holder.scad, line 704
WARNING: ceil() parameter could not be converted: argument 0: expected number, found undefined (undef) in file gridfinity_item_holder.scad, line 704
WARNING: max() parameter could not be converted: argument 0: expected number, found undefined (undef) in file modules/functions_gridfinity.scad, line 40
ERROR: Assertion 'is_num(magnet_depth)' failed: "magnet_depth must be a number" in file modules/functions_gridfinity.scad, line 49
TRACE: called by 'calculateFloorHeight' in file modules/functions_gridfinity.scad, line 62
TRACE: called by 'calculateFloorThickness' in file gridfinity_item_holder.scad, line 707
TRACE: assignment to 'ft' in file gridfinity_item_holder.scad, line 707
TRACE: called by 'gridfinity_itemholder' in file gridfinity_item_holder.scad, line 827
```

I ran a bisect and 114b7ee is the latest commit that works for me. Tested with the latest openscad git, https://github.com/openscad/openscad/commit/5e8738563c61ec53ff51e995f912f0b57754ecf6

petervk, 2024-12-31:
Same here, thanks for all your great work but also can't get the default item holder to work. Here is the error I get:

```
OpenSCAD 2024.12.30
https://www.openscad.org/

Copyright (C) 2009-2024 The OpenSCAD Developers
This program is free software; you can redistribute it and/or modify it under the terms of the GNU General Public License as published by the Free Software Foundation; either version 2 of the License, or (at your option) any later version.

Loaded design 'C:/Users/peter/OneDrive/3D Printer/gridfinity_extended_openscad/gridfinity_item_holder.scad'.
Used file cache size: 6 files
Compiling design (CSG Tree generation)...
ECHO: "•••••• UB (USER library v2022) included! v.gd/ubaer  ••••••
• Version: β23.305 v [2024, 12, 30] • Design: 0
Layer: 0.08(24.37%) Nozzle ∅: 0.4 • fn:36 fs:0.75 fa:10 • Spiel: 0.2 •"
ECHO: "❌••••• Help off       use: helpsw=1;  •••••"
ECHO: "Schalter•
 messpunkt=🟢✔ • vp=❌ • anima=❌ • help=❌ • $info=🟢✔ • bed=❌ • hires=❌ •"
ECHO: "
---————————————————————————————————————————---
"
[WARNING: Ignoring unknown variable 'magnet_diameter' in file gridfinity_item_holder.scad, line 606](https://github.com/ostat/gridfinity_extended_openscad/issues/606,C:/Users/peter/OneDrive/3D%20Printer/gridfinity_extended_openscad/gridfinity_item_holder.scad)
[WARNING: Ignoring unknown variable 'screw_depth' in file gridfinity_item_holder.scad, line 608](https://github.com/ostat/gridfinity_extended_openscad/issues/608,C:/Users/peter/OneDrive/3D%20Printer/gridfinity_extended_openscad/gridfinity_item_holder.scad)
[WARNING: Ignoring unknown variable 'center_magnet_diameter' in file gridfinity_item_holder.scad, line 609](https://github.com/ostat/gridfinity_extended_openscad/issues/609,C:/Users/peter/OneDrive/3D%20Printer/gridfinity_extended_openscad/gridfinity_item_holder.scad)
[WARNING: Ignoring unknown variable 'center_magnet_thickness' in file gridfinity_item_holder.scad, line 610](https://github.com/ostat/gridfinity_extended_openscad/issues/610,C:/Users/peter/OneDrive/3D%20Printer/gridfinity_extended_openscad/gridfinity_item_holder.scad)
[WARNING: undefined operation (undefined > number) in file gridfinity_item_holder.scad, line 695](https://github.com/ostat/gridfinity_extended_openscad/issues/695,C:/Users/peter/OneDrive/3D%20Printer/gridfinity_extended_openscad/gridfinity_item_holder.scad)
[WARNING: max() parameter could not be converted: argument 1: expected number, found undefined (undef) in file modules/functions_gridfinity.scad, line 40](https://github.com/ostat/gridfinity_extended_openscad/issues/40,C:/Users/peter/OneDrive/3D%20Printer/gridfinity_extended_openscad/modules/functions_gridfinity.scad)
[WARNING: max() parameter could not be converted: argument 1: expected number, found undefined (undef) in file modules/functions_gridfinity.scad, line 40](https://github.com/ostat/gridfinity_extended_openscad/issues/40,C:/Users/peter/OneDrive/3D%20Printer/gridfinity_extended_openscad/modules/functions_gridfinity.scad)
[WARNING: undefined operation (undefined + number) in file modules/functions_gridfinity.scad, line 43](https://github.com/ostat/gridfinity_extended_openscad/issues/43,C:/Users/peter/OneDrive/3D%20Printer/gridfinity_extended_openscad/modules/functions_gridfinity.scad)
[WARNING: undefined operation (undefined + number) in file gridfinity_item_holder.scad, line 704](https://github.com/ostat/gridfinity_extended_openscad/issues/704,C:/Users/peter/OneDrive/3D%20Printer/gridfinity_extended_openscad/gridfinity_item_holder.scad)
[WARNING: undefined operation (undefined / number) in file gridfinity_item_holder.scad, line 704](https://github.com/ostat/gridfinity_extended_openscad/issues/704,C:/Users/peter/OneDrive/3D%20Printer/gridfinity_extended_openscad/gridfinity_item_holder.scad)
[WARNING: ceil() parameter could not be converted: argument 0: expected number, found undefined (undef) in file gridfinity_item_holder.scad, line 704](https://github.com/ostat/gridfinity_extended_openscad/issues/704,C:/Users/peter/OneDrive/3D%20Printer/gridfinity_extended_openscad/gridfinity_item_holder.scad)
[WARNING: max() parameter could not be converted: argument 0: expected number, found undefined (undef) in file modules/functions_gridfinity.scad, line 40](https://github.com/ostat/gridfinity_extended_openscad/issues/40,C:/Users/peter/OneDrive/3D%20Printer/gridfinity_extended_openscad/modules/functions_gridfinity.scad)
[ERROR: Assertion 'is_num(magnet_depth)' failed: "magnet_depth must be a number" in file modules/functions_gridfinity.scad, line 49](https://github.com/ostat/gridfinity_extended_openscad/issues/49,C:/Users/peter/OneDrive/3D%20Printer/gridfinity_extended_openscad/modules/functions_gridfinity.scad)
[TRACE: called by 'calculateFloorHeight' in file modules/functions_gridfinity.scad, line 62](https://github.com/ostat/gridfinity_extended_openscad/issues/62,C:/Users/peter/OneDrive/3D%20Printer/gridfinity_extended_openscad/modules/functions_gridfinity.scad)
[TRACE: called by 'calculateFloorThickness' in file gridfinity_item_holder.scad, line 707](https://github.com/ostat/gridfinity_extended_openscad/issues/707,C:/Users/peter/OneDrive/3D%20Printer/gridfinity_extended_openscad/gridfinity_item_holder.scad)
[TRACE: assignment to 'ft' in file gridfinity_item_holder.scad, line 707](https://github.com/ostat/gridfinity_extended_openscad/issues/707,C:/Users/peter/OneDrive/3D%20Printer/gridfinity_extended_openscad/gridfinity_item_holder.scad)
[TRACE: called by 'gridfinity_itemholder' in file gridfinity_item_holder.scad, line 827](https://github.com/ostat/gridfinity_extended_openscad/issues/827,C:/Users/peter/OneDrive/3D%20Printer/gridfinity_extended_openscad/gridfinity_item_holder.scad)
Compiling design (CSG Products generation)...
Geometries in cache: 0
Geometry cache size in bytes: 0
CGAL Polyhedrons in cache: 0
CGAL cache size in bytes: 0
Compiling design (CSG Products normalization)...
Normalized tree has 1 elements!
Compile and preview finished.
Total rendering time: 0:00:00.101
```

ostat, 2025-01-04:
This should now be working

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

flaviut, 2025-01-04:
Confirmed to be fixed for me too! thank you so much!

ostat, 2025-01-04:
Thanks for confirming. It's appreciated.

petervk, 2025-01-04:
Yes, this fixed it for me also. Thank you!

Closed 2025-01-04.

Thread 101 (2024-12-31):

ItemHolder - Several issues after item holder refactoring

shrestha-pranav, 2024-12-31:
Seems like `gridfinity_item_holder` is completely broken right now. This is on the latest commit on main using the default build parameters, running `OpenSCAD Version: 2024.09.20 (git 4b645fc30)`

```
OpenSCAD 2024.09.20
https://www.openscad.org/

Copyright (C) 2009-2024 The OpenSCAD Developers
This program is free software; you can redistribute it and/or modify it under the terms of the GNU General Public License as published by the Free Software Foundation; either version 2 of the License, or (at your option) any later version.

Loaded design '<path>/gridfinity_extended_openscad/gridfinity_item_holder.scad'.
Used file cache size: 6 files
Compiling design (CSG Tree generation)...
ECHO: "•••••• UB (USER library v2022) included! v.gd/ubaer  ••••••
• Version: β23.305 v [2024, 9, 20] • Design: 0
Layer: 0.08(24.37%) Nozzle ∅: 0.4 • fn:36 fs:0.75 fa:10 • Spiel: 0.2 •"
ECHO: "❌••••• Help off       use: helpsw=1;  •••••"
ECHO: "Schalter•
 messpunkt=🟢✔ • vp=❌ • anima=❌ • help=❌ • $info=🟢✔ • bed=❌ • hires=❌ •"
ECHO: "
---————————————————————————————————————————---
"
WARNING: Ignoring unknown variable 'magnet_diameter' in file gridfinity_item_holder.scad, line 606
WARNING: Ignoring unknown variable 'screw_depth' in file gridfinity_item_holder.scad, line 608
WARNING: Ignoring unknown variable 'center_magnet_diameter' in file gridfinity_item_holder.scad, line 609
WARNING: Ignoring unknown variable 'center_magnet_thickness' in file gridfinity_item_holder.scad, line 610
WARNING: undefined operation (undefined > number) in file gridfinity_item_holder.scad, line 695
WARNING: max() parameter could not be converted: argument 1: expected number, found undefined (undef) in file modules/functions_gridfinity.scad, line 40
WARNING: max() parameter could not be converted: argument 1: expected number, found undefined (undef) in file modules/functions_gridfinity.scad, line 40
WARNING: undefined operation (undefined + number) in file modules/functions_gridfinity.scad, line 43
WARNING: undefined operation (undefined + number) in file gridfinity_item_holder.scad, line 704
WARNING: undefined operation (undefined / number) in file gridfinity_item_holder.scad, line 704
WARNING: ceil() parameter could not be converted: argument 0: expected number, found undefined (undef) in file gridfinity_item_holder.scad, line 704
ERROR: Assertion 'is_num(magnet_depth)' failed: "magnet_depth must be a number" in file modules/functions_gridfinity.scad, line 49
TRACE: called by 'calculateFloorHeight' in file modules/functions_gridfinity.scad, line 62
TRACE: called by 'calculateFloorThickness' in file gridfinity_item_holder.scad, line 707
TRACE: assignment to 'ft' in file gridfinity_item_holder.scad, line 707
TRACE: called by 'gridfinity_itemholder' in file gridfinity_item_holder.scad, line 827
Compiling design (CSG Products generation)...
Geometries in cache: 0
Geometry cache size in bytes: 0
CGAL Polyhedrons in cache: 0
CGAL cache size in bytes: 0
Compiling design (CSG Products normalization)...
Normalized tree has 1 elements!
Compile and preview finished.
Total rendering time: 0:00:00.041

Parsing design (AST generation)...
Compiling design (CSG Tree generation)...
ECHO: "•••••• UB (USER library v2022) included! v.gd/ubaer  ••••••
• Version: β23.305 v [2024, 9, 20] • Design: 0
Layer: 0.08(24.37%) Nozzle ∅: 0.4 • fn:72 fs:0.2 fa:1 • Spiel: 0.2 •"
ECHO: "❌••••• Help off       use: helpsw=1;  •••••"
ECHO: "Schalter•
 messpunkt=❌ • vp=🟢✔ • anima=❌ • help=❌ • $info=❌ • bed=❌ • hires=❌ •"
ECHO: "
    Viewportcontrol vpr: [55, 0, 25]
    Viewportcontrol vpt: [0, 0, 0]
    Viewportcontrol vpd: 140
    Viewportcontrol vpf: 22.5
    ••••  vp=on  •••••"
ECHO: "
        ⏳ Rendering…wait! ⌛"
ECHO: "
---————————————————————————————————————————---
"
WARNING: Ignoring unknown variable 'magnet_diameter' in file gridfinity_item_holder.scad, line 606
WARNING: Ignoring unknown variable 'screw_depth' in file gridfinity_item_holder.scad, line 608
WARNING: Ignoring unknown variable 'center_magnet_diameter' in file gridfinity_item_holder.scad, line 609
WARNING: Ignoring unknown variable 'center_magnet_thickness' in file gridfinity_item_holder.scad, line 610
WARNING: undefined operation (undefined > number) in file gridfinity_item_holder.scad, line 695
WARNING: max() parameter could not be converted: argument 1: expected number, found undefined (undef) in file modules/functions_gridfinity.scad, line 40
WARNING: max() parameter could not be converted: argument 1: expected number, found undefined (undef) in file modules/functions_gridfinity.scad, line 40
WARNING: undefined operation (undefined + number) in file modules/functions_gridfinity.scad, line 43
WARNING: undefined operation (undefined + number) in file gridfinity_item_holder.scad, line 704
WARNING: undefined operation (undefined / number) in file gridfinity_item_holder.scad, line 704
WARNING: ceil() parameter could not be converted: argument 0: expected number, found undefined (undef) in file gridfinity_item_holder.scad, line 704
ERROR: Assertion 'is_num(magnet_depth)' failed: "magnet_depth must be a number" in file modules/functions_gridfinity.scad, line 49
TRACE: called by 'calculateFloorHeight' in file modules/functions_gridfinity.scad, line 62
TRACE: called by 'calculateFloorThickness' in file gridfinity_item_holder.scad, line 707
TRACE: assignment to 'ft' in file gridfinity_item_holder.scad, line 707
TRACE: called by 'gridfinity_itemholder' in file gridfinity_item_holder.scad, line 827
Rendering Polygon Mesh using Manifold...
WARNING: No top level geometry to render
```

From a rough look, a lot of variables are undefined after a previous refactoring. Not sure if this is a known issue.

Are there any known good commits I can revert to?

shrestha-pranav, 2024-12-31:
Seems like `combined/gridfinity_item_holder.scad` is the new `gridfinity_item_holder.scad`. Is this a temporary change? If not, maybe removing the original file or documenting this somewhere may be better :)

shrestha-pranav, 2025-01-02:
PR #69 and #70 probably fix the issues here. Now I see this error though. Should I stick to `combined/`? Any insights would be greatly appreciated.

```
OpenSCAD 2024.09.20
https://www.openscad.org/

Copyright (C) 2009-2024 The OpenSCAD Developers
This program is free software; you can redistribute it and/or modify it under the terms of the GNU General Public License as published by the Free Software Foundation; either version 2 of the License, or (at your option) any later version.

Loaded design '/Users/ps2958/3d/gridfinity_extended_openscad/gridfinity_item_holder.scad'.
Used file cache size: 6 files
Compiling design (CSG Tree generation)...
ECHO: "•••••• UB (USER library v2022) included! v.gd/ubaer  ••••••
• Version: β23.305 v [2024, 9, 20] • Design: 0
Layer: 0.08(24.37%) Nozzle ∅: 0.4 • fn:36 fs:0.75 fa:10 • Spiel: 0.2 •"
ECHO: "❌••••• Help off       use: helpsw=1;  •••••"
ECHO: "Schalter•
 messpunkt=🟢✔ • vp=❌ • anima=❌ • help=❌ • $info=🟢✔ • bed=❌ • hires=❌ •"
ECHO: "
---————————————————————————————————————————---
"
[WARNING: variable position not specified as parameter in file gridfinity_item_holder.scad, line 734](https://github.com/ostat/gridfinity_extended_openscad/issues/734,/Users/ps2958/3d/gridfinity_extended_openscad/gridfinity_item_holder.scad)
ECHO: "🟩width: 2gf (84mm)", input = [2, 0], roundedCalcUnits = 2
ECHO: "🟩depth: 1gf (42mm)", input = [1, 0], roundedCalcUnits = 1
ECHO: "🟩height: 2.1gf (14.7mm)", input = 2.1
ECHO: "cutout_pattern", patternVariable = 0.75
ECHO: " true Grid Gridsize([2, 2, 1])=4 elements= 13.547×12×0mm
 element spacing= [13.547, 12, 0] mm
	X -6.7735 ⇔ 6.7735 mm
	Y -6 ⇔ 6 mm
	Z 0 ⇔ 0 mm"
ECHO: "cutout_pattern", patternVariable = 0.75
ECHO: " true Grid Gridsize([2, 2, 1])=4 elements= 13.547×12×0mm
 element spacing= [13.547, 12, 0] mm
	X -6.7735 ⇔ 6.7735 mm
	Y -6 ⇔ 6 mm
	Z 0 ⇔ 0 mm"
[WARNING: Ignoring unknown variable '$num_x' in file modules/module_gridfinity_cup_base_text.scad, line 51](https://github.com/ostat/gridfinity_extended_openscad/issues/51,/Users/ps2958/3d/gridfinity_extended_openscad/modules/module_gridfinity_cup_base_text.scad)
[WARNING: Ignoring unknown variable '$num_y' in file modules/module_gridfinity_cup_base_text.scad, line 53](https://github.com/ostat/gridfinity_extended_openscad/issues/53,/Users/ps2958/3d/gridfinity_extended_openscad/modules/module_gridfinity_cup_base_text.scad)
[WARNING: Ignoring unknown variable '$num_z' in file modules/module_gridfinity_cup_base_text.scad, line 55](https://github.com/ostat/gridfinity_extended_openscad/issues/55,/Users/ps2958/3d/gridfinity_extended_openscad/modules/module_gridfinity_cup_base_text.scad)
[WARNING: Experimental builtin function 'textmetrics' is not enabled in file modules/module_gridfinity_cup_base_text.scad, line 59](https://github.com/ostat/gridfinity_extended_openscad/issues/59,/Users/ps2958/3d/gridfinity_extended_openscad/modules/module_gridfinity_cup_base_text.scad)
[WARNING: Ignoring unknown function 'textmetrics' in file modules/module_gridfinity_cup_base_text.scad, line 59](https://github.com/ostat/gridfinity_extended_openscad/issues/59,/Users/ps2958/3d/gridfinity_extended_openscad/modules/module_gridfinity_cup_base_text.scad)
[WARNING: undefined operation (number / undefined) in file modules/module_gridfinity_cup_base_text.scad, line 60](https://github.com/ostat/gridfinity_extended_openscad/issues/60,/Users/ps2958/3d/gridfinity_extended_openscad/modules/module_gridfinity_cup_base_text.scad)
ECHO: " true Grid Gridsize([10, 4, 1])=40 elements= 67.0304×25.8×0mm
 element spacing= [7.44782, 8.6, 0] mm
	X -33.5152 ⇔ 33.5152 mm
	Y -12.9 ⇔ 12.9 mm
	Z 0 ⇔ 0 mm"
ECHO: " true HexGrid elements=35"
Compiling design (CSG Products generation)...
Geometries in cache: 91
Geometry cache size in bytes: 711840
CGAL Polyhedrons in cache: 30
CGAL cache size in bytes: 0
Compiling design (CSG Products normalization)...
Normalized tree has 478 elements!
Compile and preview finished.
Total rendering time: 0:00:00.240
```

Maybe I need to update my OpenSCAD version.

ostat, 2025-01-02:
Hi, yes sorry I broke it.
I should have a fix up later today, I have it mostly resolved but there was an alignment issue I need to resolve.

If you need it sooner, try the combined script, or the version on makerworld. As this might be a bit older.

Sorry for the inconvenience.

ostat, 2025-01-04:
The item holder script should now be working, there were a lot of changes needed, let me know if I missed anything
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

akavlie, 2025-01-11:
I'm having issues with this script; it often breaks depending on the item I'm trying to render or the size.
For instance, if I increase the depth past 1.0, it fails to render.

I'm using the combined version, generated 2025-01-04 at 10:13.

Closed 2025-01-10.

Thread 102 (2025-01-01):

base plate - magnets dont align correctly when when there is pre fill

ostat, 2025-01-01:
the magnets are not aligned correctly.

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

ostat, 2025-01-01:
this has been fixed b7dc631
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

Closed 2025-01-01.

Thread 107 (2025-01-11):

Error when applying wall pattern to dividers

akavlie, 2025-01-11:
I get an error when I try to apply a wall pattern to a divider. The bin fails to render.

Version: `Combined version of 'gridfinity_basic_cup.scad'. Generated 2025-01-04 09:07`

Console logs:

```
Parsing design (AST generation)...
Compiling design (CSG Tree generation)...
ECHO: "•••••• UB (USER library v2022) included! v.gd/ubaer  ••••••
• Version: β23.305 v [2025, 1, 10] • Design: 0
Layer: 0.08(24.37%) Nozzle ∅: 0.4 • fn:36 fs:0.75 fa:10 • Spiel: 0.2 •"
ECHO: "❌••••• Help off       use: helpsw=1;  •••••"
ECHO: "Schalter•
 messpunkt=🟢✔ • vp=❌ • anima=❌ • help=❌ • $info=🟢✔ • bed=❌ • hires=❌ •"
ECHO: "
---————————————————————————————————————————---
"
ECHO: "🟩height: 12gf (84mm)", input = [12, 0], roundedCalcUnits = 12
ECHO: "🟩width: 1gf (42mm)", input = [1, 0], roundedCalcUnits = 1
ECHO: "🟩depth: 1gf (42mm)", input = [1, 0], roundedCalcUnits = 1
ECHO: "🟩height: 12gf (84mm)", input = [12, 0], roundedCalcUnits = 12
ECHO: "🟩width: 1gf (42mm)", input = [1, 0], roundedCalcUnits = 1
ECHO: "🟩depth: 1gf (42mm)", input = [1, 0], roundedCalcUnits = 1
ECHO: "🟩height: 12gf (84mm)", input = [12, 0], roundedCalcUnits = 12
ECHO: "cutout_pattern", patternVariable = 0.75
ECHO: " true Grid Gridsize([14, 6, 1])=84 elements= 78.8083×35×0mm
 element spacing= [6.06218, 7, 0] mm
	X -39.4042 ⇔ 39.4042 mm
	Y -17.5 ⇔ 17.5 mm
	Z 0 ⇔ 0 mm"
ECHO: "cutout_pattern", patternVariable = 0.75
ECHO: " true Grid Gridsize([14, 6, 1])=84 elements= 78.8083×35×0mm
 element spacing= [6.06218, 7, 0] mm
	X -39.4042 ⇔ 39.4042 mm
	Y -17.5 ⇔ 17.5 mm
	Z 0 ⇔ 0 mm"
ECHO: "cutout_pattern", patternVariable = 0.75
ECHO: " true Grid Gridsize([14, 6, 1])=84 elements= 78.8083×35×0mm
 element spacing= [6.06218, 7, 0] mm
	X -39.4042 ⇔ 39.4042 mm
	Y -17.5 ⇔ 17.5 mm
	Z 0 ⇔ 0 mm"
ECHO: "cutout_pattern", patternVariable = 0.75
ECHO: " true Grid Gridsize([14, 6, 1])=84 elements= 78.8083×35×0mm
 element spacing= [6.06218, 7, 0] mm
	X -39.4042 ⇔ 39.4042 mm
	Y -17.5 ⇔ 17.5 mm
	Z 0 ⇔ 0 mm"
WARNING: Ignoring unknown variable "left" in file gridfinitybasiccup.scad, line 947
WARNING: Unable to convert translate(undef) parameter to a vec3 or vec2 of numbers in file gridfinitybasiccup.scad, line 947
WARNING: Ignoring unknown variable "left" in file gridfinitybasiccup.scad, line 948
WARNING: Problem converting rotate(a=undef) parameter in file gridfinitybasiccup.scad, line 948
WARNING: Ignoring unknown variable "left" in file gridfinitybasiccup.scad, line 954
WARNING: variable "voronoiNoise" not specified as parameter in file gridfinitybasiccup.scad, line 952
WARNING: variable "voronoiRadius" not specified as parameter in file gridfinitybasiccup.scad, line 952
ECHO: "cutout_pattern", patternVariable = 0
WARNING: undefined operation (undefined - number) in file gridfinitybasiccup.scad, line 2111
WARNING: undefined operation (undefined / number) in file gridfinitybasiccup.scad, line 2111
WARNING: undefined operation (undefined + number) in file gridfinitybasiccup.scad, line 2111
WARNING: floor() parameter could not be converted: argument 0: expected number, found undefined (undef) in file gridfinitybasiccup.scad, line 2111
WARNING: undefined operation (undefined + number) in file gridfinitybasiccup.scad, line 2113
WARNING: undefined operation (undefined / number) in file gridfinitybasiccup.scad, line 2113
WARNING: undefined operation (undefined - number) in file gridfinitybasiccup.scad, line 2113
WARNING: undefined operation (undefined * number) in file gridfinitybasiccup.scad, line 2113
WARNING: floor() parameter could not be converted: argument 0: expected number, found undefined (undef) in file gridfinitybasiccup.scad, line 2113
WARNING: undefined operation (undefined / number) in file gridfinitybasiccup.scad, line 2113
WARNING: undefined operation (undefined + number) in file gridfinitybasiccup.scad, line 2119
WARNING: undefined operation (undefined / number) in file gridfinitybasiccup.scad, line 2119
WARNING: floor() parameter could not be converted: argument 0: expected number, found undefined (undef) in file gridfinitybasiccup.scad, line 2119
WARNING: undefined operation (undefined + number) in file gridfinitybasiccup.scad, line 2121
WARNING: undefined operation (undefined / number) in file gridfinitybasiccup.scad, line 2121
WARNING: floor() parameter could not be converted: argument 0: expected number, found undefined (undef) in file gridfinitybasiccup.scad, line 2121
WARNING: undefined operation (undefined <= number) in file gridfinitybasiccup.scad, line 2125
WARNING: undefined operation (undefined <= number) in file gridfinitybasiccup.scad, line 2126
WARNING: undefined operation (undefined * undefined) in file gridfinitybasiccup.scad, line 2129
WARNING: undefined operation (undefined % number) in file gridfinitybasiccup.scad, line 2129
WARNING: ceil() parameter could not be converted: argument 0: expected number, found undefined (undef) in file gridfinitybasiccup.scad, line 2129
WARNING: undefined operation (undefined * undefined) in file gridfinitybasiccup.scad, line 2130
ERROR: Assertion '(is_list(canvasSize) && (len(canvasSize) == 2))' failed: "canvasSize must be list of len 2" in file gridfinitybasiccup.scad, line 2059
TRACE: called by 'assert' in file gridfinitybasiccup.scad, line 2059
TRACE: call of 'GridItemHolder(canvasSize = undef, hexGrid = true, customShape = false, circleFn = 6, holeSize = [5, 5], holeSpacing = [2, 2], holeGrid = [0, 0], holeHeight = 1.22, holeChamfer = 0, border = 0, center = true, fill = "crop", rotateGrid = true, help = false)' in file gridfinitybasiccup.scad, line 2057
TRACE: called by 'GridItemHolder' in file gridfinitybasiccup.scad, line 1987
TRACE: called by 'if' in file gridfinitybasiccup.scad, line 1986
TRACE: called by 'union' in file gridfinitybasiccup.scad, line 1985
TRACE: call of 'cutout_pattern(patternStyle = "hexgridrotated", canvasSize = undef, customShape = false, circleFn = 6, holeSize = [5, 5], holeSpacing = [2, 2], holeHeight = 1.22, center = true, fill = "crop", patternVariable = 0, holeRadius = undef, border = 0, help = false)' in file gridfinitybasiccup.scad, line 1977
TRACE: called by 'cutout_pattern' in file gridfinitybasiccup.scad, line 952
TRACE: called by 'difference' in file gridfinitybasiccup.scad, line 950
TRACE: called by 'render' in file gridfinitybasiccup.scad, line 949
TRACE: called by 'rotate' in file gridfinitybasiccup.scad, line 948
TRACE: called by 'translate' in file gridfinitybasiccup.scad, line 947
TRACE: called by 'translate' in file gridfinitybasiccup.scad, line 946
Compiling design (CSG Products generation)...
Geometries in cache: 176177
Geometry cache size in bytes: 52937840
CGAL Polyhedrons in cache: 289
CGAL cache size in bytes: 100293168
Compiling design (CSG Products normalization)...
Normalized tree has 1 elements!
Compile and preview finished.
Total rendering time: 0:00:00.445
```

ostat, 2025-01-24:
This error appears to be fixed, however there is a layout error for the dividers.

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

ostat, 2025-02-15:
This is now resolved.

Closed 2025-05-04.

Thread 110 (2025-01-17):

Item Holder Multi Card Slot Error

JRobynCrafts, 2025-01-17:
When trying to use Multi Card Slot feature in the item holder in makerworld, receive this error:
"Assertion 'is_num(size)' failed: "size must be a number" in file source.scad, line 33260"

rafaelfiviola, 2025-01-18:
Also happens when trying to generate the nintendo switch one

JRobynCrafts, 2025-01-21:
Also getting the same error message when selecting "Square" under custom item, itemholder hole base shape

ostat, 2025-01-24:
This issue is has been fixed

Closed 2025-02-17.

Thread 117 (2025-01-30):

Bins with Half-Sized Base

apetitjean, 2025-01-30:
Hi,

Maybe I just haven't found the functionality, but it seems there's no way to generate bins with a half-sized base.
I printed a grid with half-size cells on the border, but I can't design bins that fit in.

Is there a way to do this, or is it a current limitation of the project?

ostat, 2025-01-30:
Under the base settings there will a an option called half pitch.

https://docs.ostat.com/docs/openscad/gridfinity-extended/basic-cup/#base

apetitjean, 2025-01-30:
Thank you for your answer but this doesn't work for my case.

I opened a thread on Reddit and I joined a picture of my grid. You will understand as soon as you see it : https://www.reddit.com/r/gridfinity/comments/1idj13f/comment/m9zed1t/?context=3

ostat, 2025-01-30:
Oh I see, you are after the base plate in half pitch, I was thinking the base of the cup.

This feature is not available at the moment. It should not be needed. Full pitch and Half pitch bins fit on the standard base plate.
A halftime pitch plate will break compatibility, where a ladle pitch bin does not break compatibility and allows offsetting the bins.

That being said I would like to expose the pitch sizes (42mm and 7mm) to be configurable. This will be a while as the constants are used in a lot of places.

ostat, 2025-01-30:
I'm not sure I follow. Gridfinity extended supports half pitch bins.
You can use the official online generator at maker world which has all the options.

Perplexinglabs only supports a subset of features.

ostat, 2025-01-30:
Adding some images for clarity.

Here is a cup that is sized 3.5 units with a standard 42 mm pitch.
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

Here is the same size cup 3.5 units with a half pitch base.
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

Closed 2025-02-17.

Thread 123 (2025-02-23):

Feature request: Custom cutlery

mmalmeida, 2025-02-23:
I saw this customisable cutlery organiser for gridfinity:
https://www.printables.com/model/267303-customized-gridfinity-silverware-holder

I think this would be an awesome addition to your library.
It seems not very different from other models you already have (like the holes one).

I also see the potential to have more usages than just cutlery.

ostat, 2025-02-24:
I have an updated version of that locally for Gridfinty Extended.  However I was never happy with how it turned so have not pushed the changes.
I changed it to use dividers instead of cutouts. As this uses less plastic, and in my opinion looks cleaner.
Otherwise the cavity sizes are essentially the same I believe. I was just never happy with how the result looked.

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

mmalmeida, 2025-02-24:
That looks quite interesting actually (and I agree with you, less *plastic* is more). But I understand what you mean about not looking incredible.
I am willing to give it a go an make some tests if you publish it on makerworld - can you do it?

mmalmeida, 2025-02-24:
Step 1: publish this (I will test it).
Step 2 (crazy idea): combine this with the recently published "removable wall dividers" - make these walls removable as well :)

Monniasza, 2025-02-24:
@ostat You can create a 2d array of utensils for unlimited utensils.

ostat, 2025-02-24:
> @ostat You can create a 2d array of utensils for unlimited utensils.

The code supports a list of Utensils, where you could specify any number you wanted. You can't have an u limited list in the customiser, the ui won't support it.
Do you mean something different?

ostat, 2025-02-25:
This is what I had in mind for the removable dividers.
You can enter the number of slots to span. Then you can pick what walls to print. You cant adjust the bend position or angle.

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

mmalmeida, 2025-02-26:
This looks nice - I saw your post on reddit and will try it out.
One immediate practical issue/question: how do you recommend one mimics the "wide/narrow" distance of the other approach?
i.e I understand that the "bend" will be the number of lateral "slots" (which are based on the thickness of the removable walls), but without having tried I don't see how you can translate the "ok this spoon has 5/1cm  wide/narrow, so I need a bend of x".
What do you advise?

ostat, 2025-02-28:
> What do you advise?

The two solutions solve the problem in quite different ways. There are pros and cons depending on what you would like

Option 1: is very flexible in the layout and placement of the walls. However once its printed its fixed. So you can measure everything and get it exactly as you might like it, however once its printed its done. If you want to change it you need to reprint it.

Options 2: The removable walls, is less flexible in the position and layout of the walls, as you need to pick a set spacing. But it allows for adjusting after printing.

If I was to use option two, I would decide on my bin size, then pick my wall spacing and thickness. I might like 3mm thickness of the walls, 10mm or 15mm spacing between them.
After I print my bin, I would layout the utensils, and print what ever walls seems appropriate.  If the walls is not quite right (I printed a two step and I want a three step), or I later change my mind in the design I would just print another wall with a different step over.

>Step 2 (crazy idea): combine this with the recently published "removable wall dividers" - make these walls removable as well :)
The removable walls cant be infinity configurable. There needs to be fixed set spacing. So listing the utensil for this approach does not make sense. Maybe I'm miss understanding.

mmalmeida, 2025-03-16:
I'm playing with this today.
Here are a couple suggestions for the help labels on the parameterisation - the current text doesn't make it clear what each parameter does:

**divider wall thickness** : Thickness/protrusion to the inside of the box of the divider wall
**divider wall spanning**: Number of slot spanning dividers to generate. Walls will be generated with increasing spanning up to the selected level (e.g 3 will generate 3 walls, one with spanning 1, one with spanning 2 and one with spanning 3).

**Divider clearance** - I don't yet understand what this one does :)

mmalmeida, 2025-03-17:
@ostat - can you explain what Divider clearance does?

and also, is the base of the cup supposed to be printed with stripes (like slots for the walls to rest in? if so, what controls the depth of these stripes?

mmalmeida, 2025-03-17:
and also, is it possible to add a parameter to tell where in the wall the bend should be?
It could be absolute units or from 0-1.
e.g. 0.5 the curve is at half the wall (so if the wall has size 2, bend will be at 1) - this seems to be the current behaviour
0.9: the curve will be almost at the top

ostat, 2025-03-30:
Sorry for the delay in response.
> **divider wall thickness** : Thickness/protrusion to the inside of the box of the divider wall

The **divider wall thickness**  is the thickness of the actual wall, not how far the support comes in to the bin.

**divider wall spanning**: Number of slot spanning dividers to generate. Walls will be generated with increasing spanning up to the selected level. (e.g 3 will generate 3 walls, one with spanning 1, one with spanning 2 and one with spanning 3).

I like your suggestion, I will update, thanks for the input.

> **Divider clearance** - I don't yet understand what this one does :)

Is the clearance between the slot and the removable wall. For example, if you have `divider wall thickness = 2` the wall and the slot will be 2mm. If the clearance is 0.2, the slot will stay at 2mm and the wall will reduce to 1.8mm. This allows for a nicer fit. The reason I reduce the wall and not the slot is because its easier to reprint the walls over the bin. There are two value one is the width of the wall one is the length.

> and also, is the base of the cup supposed to be printed with stripes (like slots for the walls to rest in? if so, what controls the depth of these stripes?

Yes, the slots wont cut in to the cup wall, instead the divider wall support thickness would be added to those walls. You can increase this thickness. For example, say the cup has 1.5mm walls, and you add removable slots with 2mm supports. The outer wall to inner support is 3.5mm, the depth of the slot is 2mm.

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

Good idea, will add.

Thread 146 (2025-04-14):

Feature Request: drawer spacers for baseplate

lucamarchiori, 2025-04-14:
The idea behind this proposal is to specify the dimensions (DxW) of a drawer and automatically generate the baseplate grid (splitted according to the print bed size) and a set of spacers such that the baseplate do not slip around in the drawer.

Spacers shapes could be:
- Rectangular: to be placed at the top/bottom/left/right side of the baseplate
- Angular (L shape): to be placed in the 4 corners of the baseplate

Spacers dimensions could be:
- With: according to the difference between the baseplate and the drawer border (/2)
- Length: partial or full
- Height: same as baseplate

Let me know if someone is interested in this, i can try to provide a PR even though i am not proficient with OpenScad

ostat, 2025-05-04:
This is essentially supported I think.
You set the desired size, and the print bed size and the base plate is auto split as needed. If the space is not exactly a multiple of 42, sub grid spaces are created.

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

Regarding the spacers, so I can better understand what would the use case be that the current feature would not support? What is the issue we are trying to fix?
Is for when there are things that stick in to the drawer? like a screw or hinge, and you need some clearance?

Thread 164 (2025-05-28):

Is there a getting started somewhere?

haemi, 2025-05-28:
when I open e.g. gridfinity_item_holder.scad and render it, I get

```
[ERROR: Assertion 'is_bool(settings[iDividerRemovable_Enabled])' failed: "Divider Removable Enabled must be a boolean" in file module_gridfinity_dividers_removable.scad, line 41](https://github.com/ostat/gridfinity_extended_openscad/issues/41,/Users/stefan/Developer/3rdparty/gridfinity_extended_openscad/modules/module_gridfinity_dividers_removable.scad)
[TRACE: called by 'ValidateDividerRemovableSettings' in file module_gridfinity_dividers_removable.scad, line 34](https://github.com/ostat/gridfinity_extended_openscad/issues/34,/Users/stefan/Developer/3rdparty/gridfinity_extended_openscad/modules/module_gridfinity_dividers_removable.scad)
[TRACE: called by 'DividerRemovableSettings' in file module_gridfinity_cup.scad, line 277](https://github.com/ostat/gridfinity_extended_openscad/issues/277,/Users/stefan/Developer/3rdparty/gridfinity_extended_openscad/modules/module_gridfinity_cup.scad)
[TRACE: called by 'gridfinity_cup' in file gridfinity_item_holder.scad, line 773](https://github.com/ostat/gridfinity_extended_openscad/issues/773,/Users/stefan/Developer/3rdparty/gridfinity_extended_openscad/gridfinity_item_holder.scad)
[TRACE: called by 'difference' in file gridfinity_item_holder.scad, line 771](https://github.com/ostat/gridfinity_extended_openscad/issues/771,/Users/stefan/Developer/3rdparty/gridfinity_extended_openscad/gridfinity_item_holder.scad)
[TRACE: called by 'if' in file gridfinity_item_holder.scad, line 769](https://github.com/ostat/gridfinity_extended_openscad/issues/769,/Users/stefan/Developer/3rdparty/gridfinity_extended_openscad/gridfinity_item_holder.scad)
[TRACE: called by 'gridfinity_itemholder' in file gridfinity_item_holder.scad, line 917](https://github.com/ostat/gridfinity_extended_openscad/issues/917,/Users/stefan/Developer/3rdparty/gridfinity_extended_openscad/gridfinity_item_holder.scad)
[TRACE: called by 'children' in file modules/functions_environment.scad, line 47](https://github.com/ostat/gridfinity_extended_openscad/issues/47,/Users/stefan/Developer/3rdparty/gridfinity_extended_openscad/modules/functions_environment.scad)
[TRACE: called by 'difference' in file modules/functions_environment.scad, line 45](https://github.com/ostat/gridfinity_extended_openscad/issues/45,/Users/stefan/Developer/3rdparty/gridfinity_extended_openscad/modules/functions_environment.scad)
[TRACE: called by 'union' in file modules/functions_environment.scad, line 44](https://github.com/ostat/gridfinity_extended_openscad/issues/44,/Users/stefan/Developer/3rdparty/gridfinity_extended_openscad/modules/functions_environment.scad)
[TRACE: called by 'translate' in file modules/functions_environment.scad, line 43](https://github.com/ostat/gridfinity_extended_openscad/issues/43,/Users/stefan/Developer/3rdparty/gridfinity_extended_openscad/modules/functions_environment.scad)
[TRACE: called by 'set_environment' in file gridfinity_item_holder.scad, line 909](https://github.com/ostat/gridfinity_extended_openscad/issues/909,/Users/stefan/Developer/3rdparty/gridfinity_extended_openscad/gridfinity_item_holder.scad)
Compiling design (CSG Products generation)...
Geometries in cache: 71
Geometry cache size in bytes: 668384
CGAL Polyhedrons in cache: 35
CGAL cache size in bytes: 16611440
Compiling design (CSG Products normalization)...
Normalized tree has 1 elements!
Compile and preview finished.
Total rendering time: 0:00:00.059

Parsing design (AST generation)...
Compiling design (CSG Tree generation)...
ECHO: "🟩width: 2gf (84mm)", input = [2, 0], roundedCalcUnits = 2
ECHO: "🟩depth: 1gf (42mm)", input = [1, 0], roundedCalcUnits = 1
ECHO: "🟩height: 3gf (21mm)", input = [3, 0], roundedCalcUnits = 3
ECHO: "🟩set_environment", fs = 0.1, fa = 6, fn = 0, pitch = [42, 42, 7]
[WARNING: Ignoring unknown variable 'divider_clearance' in file modules/module_gridfinity_cup.scad, line 285](https://github.com/ostat/gridfinity_extended_openscad/issues/285,/Users/stefan/Developer/3rdparty/gridfinity_extended_openscad/modules/module_gridfinity_cup.scad)
[WARNING: Ignoring unknown variable 'divider_walls_thickness' in file modules/module_gridfinity_cup.scad, line 284](https://github.com/ostat/gridfinity_extended_openscad/issues/284,/Users/stefan/Developer/3rdparty/gridfinity_extended_openscad/modules/module_gridfinity_cup.scad)
[WARNING: Ignoring unknown variable 'divider_walls_spacing' in file modules/module_gridfinity_cup.scad, line 283](https://github.com/ostat/gridfinity_extended_openscad/issues/283,/Users/stefan/Developer/3rdparty/gridfinity_extended_openscad/modules/module_gridfinity_cup.scad)
[WARNING: Ignoring unknown variable 'divider_slot_spanning' in file modules/module_gridfinity_cup.scad, line 286](https://github.com/ostat/gridfinity_extended_openscad/issues/286,/Users/stefan/Developer/3rdparty/gridfinity_extended_openscad/modules/module_gridfinity_cup.scad)
[WARNING: Ignoring unknown variable 'divider_headroom' in file modules/module_gridfinity_cup.scad, line 280](https://github.com/ostat/gridfinity_extended_openscad/issues/280,/Users/stefan/Developer/3rdparty/gridfinity_extended_openscad/modules/module_gridfinity_cup.scad)
[WARNING: Ignoring unknown variable 'divider_wall_slot_size' in file modules/module_gridfinity_cup.scad, line 282](https://github.com/ostat/gridfinity_extended_openscad/issues/282,/Users/stefan/Developer/3rdparty/gridfinity_extended_openscad/modules/module_gridfinity_cup.scad)
[WARNING: Ignoring unknown variable 'divider_walls' in file modules/module_gridfinity_cup.scad, line 279](https://github.com/ostat/gridfinity_extended_openscad/issues/279,/Users/stefan/Developer/3rdparty/gridfinity_extended_openscad/modules/module_gridfinity_cup.scad)
[WARNING: Ignoring unknown variable 'divider_walls_support_thickness' in file modules/module_gridfinity_cup.scad, line 281](https://github.com/ostat/gridfinity_extended_openscad/issues/281,/Users/stefan/Developer/3rdparty/gridfinity_extended_openscad/modules/module_gridfinity_cup.scad)
[WARNING: Ignoring unknown variable 'divider_walls_enabled' in file modules/module_gridfinity_cup.scad, line 278](https://github.com/ostat/gridfinity_extended_openscad/issues/278,/Users/stefan/Developer/3rdparty/gridfinity_extended_openscad/modules/module_gridfinity_cup.scad)
[ERROR: Assertion 'is_bool(settings[iDividerRemovable_Enabled])' failed: "Divider Removable Enabled must be a boolean" in file module_gridfinity_dividers_removable.scad, line 41](https://github.com/ostat/gridfinity_extended_openscad/issues/41,/Users/stefan/Developer/3rdparty/gridfinity_extended_openscad/modules/module_gridfinity_dividers_removable.scad)
[TRACE: called by 'ValidateDividerRemovableSettings' in file module_gridfinity_dividers_removable.scad, line 34](https://github.com/ostat/gridfinity_extended_openscad/issues/34,/Users/stefan/Developer/3rdparty/gridfinity_extended_openscad/modules/module_gridfinity_dividers_removable.scad)
[TRACE: called by 'DividerRemovableSettings' in file module_gridfinity_cup.scad, line 277](https://github.com/ostat/gridfinity_extended_openscad/issues/277,/Users/stefan/Developer/3rdparty/gridfinity_extended_openscad/modules/module_gridfinity_cup.scad)
[TRACE: called by 'gridfinity_cup' in file gridfinity_item_holder.scad, line 773](https://github.com/ostat/gridfinity_extended_openscad/issues/773,/Users/stefan/Developer/3rdparty/gridfinity_extended_openscad/gridfinity_item_holder.scad)
[TRACE: called by 'difference' in file gridfinity_item_holder.scad, line 771](https://github.com/ostat/gridfinity_extended_openscad/issues/771,/Users/stefan/Developer/3rdparty/gridfinity_extended_openscad/gridfinity_item_holder.scad)
[TRACE: called by 'if' in file gridfinity_item_holder.scad, line 769](https://github.com/ostat/gridfinity_extended_openscad/issues/769,/Users/stefan/Developer/3rdparty/gridfinity_extended_openscad/gridfinity_item_holder.scad)
[TRACE: called by 'gridfinity_itemholder' in file gridfinity_item_holder.scad, line 917](https://github.com/ostat/gridfinity_extended_openscad/issues/917,/Users/stefan/Developer/3rdparty/gridfinity_extended_openscad/gridfinity_item_holder.scad)
[TRACE: called by 'children' in file modules/functions_environment.scad, line 47](https://github.com/ostat/gridfinity_extended_openscad/issues/47,/Users/stefan/Developer/3rdparty/gridfinity_extended_openscad/modules/functions_environment.scad)
[TRACE: called by 'difference' in file modules/functions_environment.scad, line 45](https://github.com/ostat/gridfinity_extended_openscad/issues/45,/Users/stefan/Developer/3rdparty/gridfinity_extended_openscad/modules/functions_environment.scad)
[TRACE: called by 'union' in file modules/functions_environment.scad, line 44](https://github.com/ostat/gridfinity_extended_openscad/issues/44,/Users/stefan/Developer/3rdparty/gridfinity_extended_openscad/modules/functions_environment.scad)
[TRACE: called by 'translate' in file modules/functions_environment.scad, line 43](https://github.com/ostat/gridfinity_extended_openscad/issues/43,/Users/stefan/Developer/3rdparty/gridfinity_extended_openscad/modules/functions_environment.scad)
[TRACE: called by 'set_environment' in file gridfinity_item_holder.scad, line 909](https://github.com/ostat/gridfinity_extended_openscad/issues/909,/Users/stefan/Developer/3rdparty/gridfinity_extended_openscad/gridfinity_item_holder.scad)
Rendering Polygon Mesh using CGAL...
Geometries in cache: 71
Geometry cache size in bytes: 668384
CGAL Polyhedrons in cache: 35
CGAL cache size in bytes: 16611440
Total rendering time: 0:00:00.505
WARNING: No top level geometry to render
```

and when I create a new file with

```
include <gridfinity-rebuilt-utility.scad>
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
jiblett1000, 2025-05-30:
Same, here. I'm at a loss. I get similar issues when opening the basic cup file. Although, nothing is rendered in my case. I would love to get this working as well.

jiblett1000, 2025-05-31:
@haemi No problem. That's totally possible. So all you'll need to do is download this github repository (e.g. gridfinity_extended_openscad) and then open the base_cup file within. Just make sure that you keep all the files together in that directory because they need to reference each other. When it opens in openscad there should be a window on the right side that has all the parameters you can modify.

Another important note that I stumbled on is that before you export to whatever format you choose, make sure to render it first otherwise it will just keep exporting the original version of the file you opened (or the last rendered version).

I'm just getting started with this myself, so that's about all I'm aware of, but of course reach out if you have any more questions.

ostat, 2025-05-31:
> ah, perfect - thanks @jiblett1000 ! What I'm still missing is how to use this now 🙂 I.e. how can I base on the basic cup but set my parameters like width and height and then do some cutouts etc. I would like to do that all in OpenSCAD, somehow import the basic cup, modify the parameters and then to the cutouts - is that possible?

Glad you got it working. If you mean cutouts as in create a bin that has a defined shape for a specific tool. Gridfinity extended is not the best tool for that.
There is a Gridfinity webpage that is suited for that.

jiblett1000, 2025-05-31:
Ah yes. I forgot to address the cutouts. A potential alternative to the web tool mentioned by @ostat would be to export the desired bin using openscad as mentioned above and then perform the boolean cutout using your slicer (assuming whatever slicer you're using has that functionality of course) or another CAD software if you have one.

Closed 2025-06-02.

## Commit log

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2023-09-25 create function SequentialBridgingDoubleHole, allow grid block to be not stackable. created modules folder
    [gridfinity_baseplate.scad, gridfinity_basic_cup.scad, gridfinity_chess.scad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]
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2023-10-27 fixed half_pitch, improved wallcutout interaction
    [gridfinity_baseplate_demo.scad, gridfinity_basic_cup.scad, gridfinity_basic_cup_demo.scad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]
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2023-10-30 cleaned up and fixed pad_grid, expanded wallpattern_fill
    [ItemSizeList.csv, gridfinity_basic_cup.scad, gridfinity_basic_cup_demo.scad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]
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2023-11-04 reworked cavity generation
    [gridfinity_constants.scad, gridfinity_cup_modules.scad, gridfinity_modules.scad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]
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2023-12-16 correct silverware position
    [gridfinity_silverware.scad]
2023-12-16 reworked cup dividers
    [gridfinity_basic_cup.scad, gridfinity_basic_cup_demo.scad, gridfinity_cup_modules.scad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]
2024-01-10 resolve the variable naming issues in baseplate.
    [gridfinity_baseplate.scad]
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2024-01-10 Fixed the pattern on the separators. added voronoi pattern.
    [gridfinity_basic_cup.scad, gridfinity_basic_cup_demo.scad, gridfinity_cup_modules.scad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]
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2024-01-29 improved attachment generation efficiently and logic for when to generate, default to dynamic wall width.
    [gridfinity_basic_cup.scad, gridfinity_basic_cup_demo.scad, gridfinity_cup_modules.scad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]
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2024-02-15 openscad preview crashes while attempting to edit
    [gridfinity_drawers.scad]
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2024-02-15 the boxes are borked and won't work
    [gridfinity_drawers.scad]
2024-02-15 fixed base and threw out minkowski
    [Bin Base - Printables model 417152.stl, gridfinity_drawers.scad]
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2024-02-17 Correct placing of wall cutout
    [gridfinity_drawers.scad]
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2024-02-20 fix typos
    [gridfinity_drawers.scad]
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2024-03-18 Add full support for fractional increments and improve socket selection (#12)
    * improved part selection
    * added fractional increments
    * remove unapplicable settings from the item holder
    ---------
    [gridfinity_basic_cup.scad, gridfinity_item_holder.scad, gridfinity_socket_holder.scad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]
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2024-04-07 restrict efficient floor slide when less than 0.3*42mm to prevent clipping
    [gridfinity_cup_modules.scad]
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2024-04-26 if num_x or num_y is greater than 21, assume its in mm.
    [gridfinity_cup_modules.scad]
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2024-05-07 Add custom size rectangle support (#25)
    * add custom rectangle size support
    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
    [gridfinity_item_holder.scad]
2024-05-18 allow configurable clearances for chest
    [gridfinity_drawers.scad]
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2024-06-17 correct position of tray
    [gridfinity_item_holder.scad]
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2024-06-23 Remove trailing comma from arrays in lid. Might be causing errors on Mac
    [gridfinity_basic_cup.scad, gridfinity_cutlerytray.scad, gridfinity_drawers.scad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]
2024-06-23 reworked spacing for custom tray spacing
    [gridfinity_tray.scad]
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2024-06-26 re added, bent wall function that should not have been removed.
    [gridfinity_basic_cup.scad, gridfinity_drawers.scad, gridfinity_item_holder.scad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]
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2024-07-06 better MakerWord support for itemholder. Spelling fixes
    [gridfinity_baseplate.scad, gridfinity_baseplate_demo.scad, gridfinity_baseplate_flsun_q5.scad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]
2024-07-11 correct typo in position dropdown
    [gridfinity_basic_cup.scad, gridfinity_item_holder.scad, gridfinity_lid.scad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]
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2024-07-27 Fix for finger slide position
    [gridfinity_cup_modules.scad]
2024-07-27 refined width and position of cutout on bentWall
    [modules_utility.scad]
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2024-08-02 correct position of base
    [module_gridfinity_baseplate.scad]
2024-08-02 efficient floor correction for partial bins
    [functions_gridfinity.scad, gridfinity_baseplate.scad, module_calipers.scad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]
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2024-08-02 correct itemholder corner radius
    [gridfinity_item_holder.scad]
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2024-08-05 for wall patters add ability to rotate the grid to improve printability
    [gridfinity_basic_cup.scad, gridfinity_drawers.scad, gridfinity_item_holder.scad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]
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2024-08-06 correct positioning of the base plate
    [gridfinity_baseplate.scad, gridfinity_basic_cup.scad, gridfinity_cutlerytray.scad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]
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2024-09-06 fixing correct placement of click label in chambers from 2 upward (#41)
    [module_gridfinity_label.scad]
2024-09-14 Correct orientation of back cutout
    [gridfinity_drawers.scad, module_item_holder.scad]
2024-09-14 remove training comma in bentWall
    [module_utility.scad]
2024-09-15 correct the wall cutout with negative values with wall pattern
    [gridfinity_basic_cup.scad, module_gridfinity_cup.scad]
2024-09-15 Wall cutout should account for label on all walls. Front and back label were swapped
    [gridfinity_basic_cup.scad, module_gridfinity_cup.scad, module_gridfinity_label.scad]
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2024-10-08 correct position of cut away side lips if num_x is less than 1
    [module_gridfinity_cup.scad]
2024-10-08 Improved wall cutout logic to more easily support full bin cutouts, and more flexible options for different horizontal and vertical cutouts
    [gridfinity_basic_cup.scad, module_gridfinity_cup.scad, module_utility.scad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]
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2024-10-10 round the dimensions to prevent floating point errors in openscad
    [functions_general.scad, functions_gridfinity.scad]
2024-10-14 fixed issue where first label was not repositioning. Optomised label positions
    [module_gridfinity_label.scad]
2024-10-14 Fix Artifact when label is enabled
    [module_gridfinity_label.scad]
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2024-11-14 Enable magnets and screws (#59)
    * WIP
    * add enable_magnets and enable_screws for the basic_cup
    [gridfinity_basic_cup.scad, module_gridfinity_cup.scad]
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2024-11-21 Spelling Fixes (#65)
    [functions_gridfinity.scad, gridfinity_baseplate.scad, gridfinity_basic_cup.scad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]
2024-11-22 rework baseplate and lid functions
    [functions_general.scad, functions_gridfinity.scad, gridfinity_baseplate.scad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]
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2024-11-22 Spelling Fix, II (#68)
    * Custome --> Custom
    * Spelling fixes
    * More spelling fixes
    [functions_general.scad, functions_gridfinity.scad, gridfinity_baseplate.scad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]
2024-11-22 correct issue where base magnet would not attach to wall if it was too small
    [module_gridfinity_baseplate_common.scad, module_gridfinity_cup.scad]
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2024-11-24 fix overhang on efficient floor
    [module_gridfinity_efficient_floor.scad]
2024-11-24 Union before loop (#67)
    As `difference` only deletes from the first child, we have to make that the union of our wall patterns
    [module_gridfinity_cup.scad]
2024-11-24 Add customizable text to bottom of bins (#73)
    First line is the size
    Second line is free-form
    [gridfinity_basic_cup.scad, gridfinity_item_holder.scad, module_gridfinity_cup.scad]
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2024-11-25 correct extendable calculation
    [module_gridfinity_cup.scad]
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2024-11-27 correct SetGridfinityEnvironment for sliding lid
    [gridfinity_sliding_lid.scad]
2024-11-27 change mode to render_choice, for clarity. Fix some bugs in the chest
    [gridfinity_drawers.scad, gridfinity_sliding_lid.scad]
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2024-11-30 correct placement for spacer cutout
    [module_gridfinity_efficient_floor.scad]
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2024-12-08 Improve comments for chest clearance options
    [gridfinity_drawers.scad]
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2025-01-01 baseplate, added magnetZOffset, correct magnet alignment for prefill, set holdown screws in corner only
    [gridfinity_baseplate.scad, module_gridfinity.scad, module_gridfinity_baseplate.scad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]
2025-01-01 correct the baseplate, render glitch
    [gridfinity_baseplate.scad, module_gridfinity.scad, module_gridfinity_baseplate_common.scad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]
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2025-01-01 Item holder bottom setting working! (#70)
    * Match item holder configuration layout to basic cup
    * Make "Itemholder hole depth" work
    [gridfinity_item_holder.scad]
2025-01-03 hide brick pattern cell if its too small
    [module_pattern_brick.scad]
2025-01-03 move the cut logic back in to cup function, as it was conflicting with the calipers
    [functions_general.scad, module_gridfinity_cup.scad]
2025-01-03 fix issues with the itemholder due to changes in basic cup. incorrect height and scripting bugs.
    [gridfinity_item_holder.scad]
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2025-01-03 correct lip alignment
    [module_gridfinity.scad, module_lip.scad]
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2025-01-06 improve performance by removing the hardcoded $fn in preference of user editable $fa and $fs
    [gridfinity_baseplate.scad, gridfinity_basic_cup.scad, gridfinity_chess.scad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]
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2025-01-11 sliding lid lip interfering with cup lip
    [module_gridfinity_sliding_lid.scad]
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2025-01-18 correct flat base logic for efficient_floor with new options
    [module_gridfinity_cup.scad, module_gridfinity_efficient_floor.scad]
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2025-01-23 add clearance to butterfly connector
    [gridfinity_baseplate.scad, module_gridfinity_baseplate_connectors.scad]
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2025-01-28 extract only the parts needed from the ub library to save on size of combined files
    [module_calipers.scad, module_gridfinity.scad, module_item_holder.scad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]
2025-01-29 correct issue where two functions have the name chamferedSquare, renamed one chamferedSquare to chamfered_cube
    [gridfinity_baseplate.scad, gridfinity_basic_cup.scad, gridfinity_cutlerytray.scad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]
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2025-02-08 module_gridfinity_baseplate, missing variable connectorFilamentLength
    [module_gridfinity_baseplate.scad]
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2025-02-12 Custom pitch (#120)
    * created functions_environment
    * Allow changing of the pitch (grid size)
    * custom_Baseplate, custom cell sizes
    * clean up help
    * label and cutout fixes for custom pitch
    [functions_environment.scad, functions_general.scad, functions_gridfinity.scad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]
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2025-02-15 replaced patternVariable with patternGridChamfer, patternVoronoiNoise, patternBrickWeight
    [gridfinity_basic_cup.scad, gridfinity_basic_cup_demo.scad, gridfinity_drawers.scad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]
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2025-02-17 updates related to lip notches, lip top relief, and a few clean up items
    [functions_environment.scad, functions_gridfinity.scad, gridfinity_basic_cup.scad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]
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2025-02-25 Dividers (#127)
    * clean up module_gridfinity_dividers_removable
    * tweak the position of the removable walls pieces
    * clean up of removable divider walls
    * generate bent walls
    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
    [gridfinity_basic_cup.scad, module_gridfinity_dividers_removable.scad]
2025-03-03 Fix calculateFloorHeight in extension feature
    [module_attachment_clip.scad, module_gridfinity_cup.scad]
2025-03-06 update itemholder so that the data value is not a number, as this does not work on makerworld
    [ItemSizeList.csv, gridfinity_item_holder.scad, module_item_holder_data.scad]
2025-03-10 correct alignment of the lip notches for half bins
    [module_lip.scad]
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2025-04-20 Fix documentation URL (#148)
    [gridfinity_basic_cup.scad, gridfinity_sliding_lid.scad]
2025-05-02 Marbel blocks (#153)
    * marble initial commit
    * Support reduced lip
    * update marble script to better handle rotate and mirror
    * Allow lip connectors on the basic block
    [__frags.scad, __ra_to_xy.scad, __to_ang_vect.scad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]
2025-05-02 Center magnet (#154)
    * Fix misaligned center magnet hole (#150)
    * Fix documentation URL (#148)
    * Fix misaligned center magnet hole
    Center magnet is being attached to corner of object instead of center of object, need to divide by half to place in center
    * re apply, center magnet correction post merge
    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
    [module_gridfinity_block.scad, module_gridfinity_frame_connectors.scad]
2025-05-03 correct floor height when screw is not enabled.
    [gridfinity_item_holder.scad]
2025-05-04 Fix issue with missing FlatBase variables
    [module_gridfinity_baseplate_lid.scad]
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2025-05-04 correct chest position_fill_grid bug
    [gridfinity_drawers.scad, module_gridfinity_baseplate.scad]
2025-05-13 add reduced_double lip style (#157)
    * add reduced_double lip style
    * Update gridfinity_basic_cup.scad
    * Update gridfinity_basic_cup.scad
    * Update modules/gridfinity_constants.scad
    * Update gridfinity_basic_cup.scad
    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
    [gridfinity_baseplate.scad, gridfinity_basic_cup.scad, gridfinity_basic_cup_demo.scad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]
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2025-07-21 set tolerance to be configurable, add option to include lip in height, support walls thicker than 3mm
    [functions_environment.scad, functions_gridfinity.scad, gridfinity_basic_cup.scad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]
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2025-08-13 rework the Stanley organiser code
    [stanley_basic_cup.scad]
2025-08-13 fix itemholder height calculation
    [gridfinity_item_holder.scad]
2025-08-13 rework the spacing of dividers so the cavity is evenly spaced
    [functions_environment.scad, functions_gridfinity.scad, module_divider_walls.scad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]
2025-08-13 add presets for tray flat_base (#185)
    a user complained in #137 that setting flat_base in gridfinity_tray wasn't behaving. i found that the customizer wasn't programmed with the appropiate values (off, gridfinity, rounded) i tested each 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
    [gridfinity_tray.scad]
2025-08-13 add captive magnet voids for cups (#183)
    * add captive magnet voids for cups
    kludge in cylindrical voids to the cup tree. customizer to enable "print-in-magnets" but no other options. the void starts at z=0.4, which is supposed to be two (bottom) layers.
    I think it would be a good idea to set a 'lh' global because some features (like the material between the magnet void and the outer surface of the object) are best calibrated to multiples to the laye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
    I did this work originally on commit 8d511b6b. rebasing took a few hours.
    * update calculateFloorHeight and change primary captive magnet setting from boolean to number
    i realized that instead of setting some kind of global layerhe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
    [functions_gridfinity.scad, gridfinity_basic_cup.scad, module_gridfinity_block.scad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]
2025-08-15 Correct the floor thickness bug in gridfinity_item_holder.
    [gridfinity_item_holder.scad]
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2025-09-04 correct the pattern length check
    [module_patterns.scad]
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2025-09-09 Fix https://github.com/ostat/gridfinity_extended_openscad/issues/191 (#192)
    Pass new cellSize and strength parameters to cutout_pattern
    [module_gridfinity_cup.scad]
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2025-09-09 Improve wallpatterns clearances.
    [module_gridfinity_cup.scad, module_patterns.scad]
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2025-09-15 correct issues caused by updated wall patterns
    [gridfinity_basic_cup.scad, gridfinity_drawers.scad, gridfinity_item_holder.scad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]
2025-09-15 More wall pattern fixes
    [gridfinity_basic_cup.scad, gridfinity_sieve.scad, gridfinity_sliding_lid.scad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]
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2025-09-17 correct baseplate issue with corner screw only, allow easy release magnets on base.
    [module_gridfinity_baseplate_common.scad, module_gridfinity_block.scad, module_magnet.scad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]
2025-09-19 added x and y offsets for under text (#204)
    * added x and y offsets for under text
    * text offset if now 1 variable
    [gridfinity_basic_cup.scad, module_gridfinity_cup.scad, module_gridfinity_cup_base_text.scad]
2025-09-19 Fixing the order of objects retracting from the main bin.
    [module_gridfinity_cup.scad, module_patterns.scad]
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2025-09-22 Correct thirdparty typo (#205)
    [module_calipers.scad, module_item_holder.scad, module_utility.scad]
2025-09-22 wall pattern divider bug fixes
    [module_bin_chambers.scad, module_gridfinity_cup.scad]
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2025-09-24 stabilise main branch
    [gridfinity_basic_cup.scad, module_patterns.scad]
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2025-10-13 missed a 2D
    [module_utility.scad]
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2025-10-14 bentWall relative values
    [module_utility.scad]
2025-10-15 clean up broken removable walls, ready for merge of new version
    [gridfinity_basic_cup.scad, module_gridfinity_cup.scad, module_gridfinity_dividers_removable.scad]
2025-10-15 correct BOM for script combining
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2025-11-08 fix extention tabs height for efficient floor
    [functions_general.scad, gridfinity_baseplate.scad, gridfinity_baseplate_flsun_q5.scad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]
2025-11-08 missed save for module_gridfinity_Extendable
    [module_gridfinity_Extendable.scad]
2025-12-28 Fix for chess. Contract of lipStyle prop was changed (#220)
    [gridfinity_chess.scad]
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2025-12-28 Fix label socket Z positioning for pred and gflabel styles (#232)
    [module_gridfinity_label.scad]
2026-01-14 added snaps connectors
    [gridfinity_baseplate.scad, module_gridfinity.scad, module_gridfinity_baseplate.scad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]
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2026-01-15 center wall snaps
    [module_gridfinity_frame_connectors.scad]
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2026-01-28 added seconder baseplate radius option (#241)
    * added seconder baseplate radius option
    * fixed small issue
    [gridfinity_baseplate.scad, module_gridfinity_baseplate.scad, module_gridfinity_baseplate_common.scad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]
2026-01-28 Fix: Allow thin magnet tabs with magnet holes by decoupling magnets from corner screws (#244)
    * Fix: Decouple magnet holes from structural screw tabs
    * Fix: magenet hole was coupled to screw hole; fixed the coupling so magnet hole does not have screw chamfer and Feat: Add 'Easy Release' checkbox and fix magnet hole logic
    * Feat: Upgrade Easy Release to dropdown (Added 'Poke Hole' option)
    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
    [gridfinity_baseplate.scad, module_gridfinity_baseplate.scad, module_gridfinity_baseplate_common.scad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]
2026-01-28 fixes an error in gridfinity_lid.scad (#245)
    [module_gridfinity_baseplate_lid.scad, module_gridfinity_cup_base.scad, module_gridfinity_lid.scad]
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2026-02-08 add commit tests, and resolve any related issues.
    [gridfinity_baseplate.scad, gridfinity_baseplate_flsun_q5.scad, gridfinity_basic_cup.scad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]
2026-02-09 replace half_pitch with sub_pitch that can be a number 1-4, 2 is half.
    [gridfinity_baseplate.scad, gridfinity_baseplate_flsun_q5.scad, gridfinity_basic_cup.scad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]
2026-02-10 added label to bent wall
    [gridfinity_baseplate.scad, gridfinity_baseplate_flsun_q5.scad, gridfinity_basic_cup.scad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]
2026-02-10 fixed bentWall label_size typo default
    [gridfinity_baseplate.scad, gridfinity_baseplate_flsun_q5.scad, gridfinity_basic_cup.scad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]
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2026-02-15 Allow PythonSCAD versions, its a pretty sloppy solution.
    [functions_general.scad, gridfinity_baseplate.scad, gridfinity_baseplate_flsun_q5.scad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]
2026-02-16 [WIP] Fix for sliding lid (#246)
    * added "both connected" for render options in sliding_lid
    * initial fix for hanging lip
    * small cleaning in module_slidining_lid and possible solution for the height problem
    [gridfinity_sliding_lid.scad, module_gridfinity_sliding_lid.scad]
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2026-02-16 clean some possible lid bugs (#259)
    [gridfinity_sliding_lid.scad, module_gridfinity_sliding_lid.scad]
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2026-02-17 added missing heading
    [gridfinity_sliding_lid.scad]
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2026-09-23 Pretty bins (#304)
    * WIP kumiko wall patterns
    * kumiko cleanup
    * doco for kumiko
    * kumiko 3d
    * removable wall patterns
    * support cut on y
    * split patterns improvements
    * removable patterns checkpoint
    * split wall patterns
    * add split back to wall pattern
    * fix asanoha pattern
    [demo.scad, gridfinity_basic_cup.scad, kumiko.scad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]
